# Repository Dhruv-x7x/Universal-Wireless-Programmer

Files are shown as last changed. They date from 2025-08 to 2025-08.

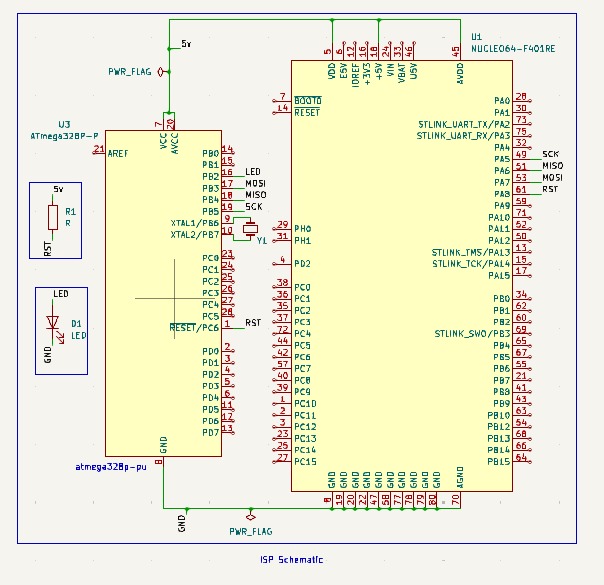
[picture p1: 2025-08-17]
others/ISP_schematic.jpeg

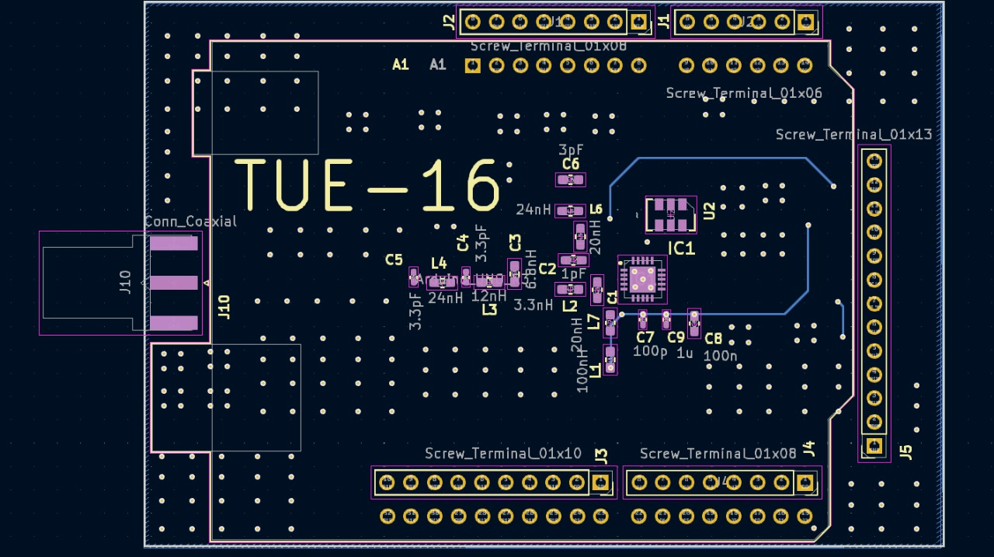
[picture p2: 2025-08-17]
pcb/PCB1/pictures/pcb_sch_back.jpeg

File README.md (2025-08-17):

Review Assignment Due Date (https://classroom.github.com/a/NJLWAR4a)
 

 
<!-- DON'T MODIFY ANYTHING ABOVE -->
<!-- Modify from here -->
## 📄 Project Documentation

###  Project Name: Universal Wireless Programmer
###  Team Number: TUE-16
###  Team Members:

Anay Malviya 22b1255

Dhruv Meena 22b1279

Hardik Pratap Gohil 22b1293

Kaustav Saha 22b1228

Saptarshi Biswas 22b1258

---

### 📌 Problem Statement and Solution:

Whether it's deep inside big industrial machines, remote terrains or disaster zones, there is always bots and embedded devices to perform critical tasks and send back important data to the users. The big limitation here is that **we have to physically access them to reprogram them and download data.** The **Universal Wireless Programmer** completely cuts off all cords as well as this big limiation. We designed a **wireless programming** and **data retrieval** system for microcontrollers and development boards like Arduino Uno and ATmega328P. We use **RF communication** to send compiled code and receive real-time data back, all over-the-air.

---

### 📚 Contents

- [src](./src) – Source code including firmware and scripts
- [pcb](./pcb) – PCB design files and schematics
- [reports](./reports) – Milestone reports
- [others](./others) – Other circuit diagrams and misc. info
- [3d_models](./3d_models) – 3D CAD files
- [README.md](./README.md) – Problem Statement
- [bom.xls](./bom.xls) – Bill of Materials

---

### 💡 Learnings
We tried a lot of approaches throughout the project to figure out programming since there were no easily available resources related to that. Firstly, we got stuck at figuring out how to make arduino enter into the bootloader mode. For that we tried a bunch of approaches:
1) Software reset - Using DTR and RTS (Failed due to no response from arduino)
2) Power reset - Using pmos (Failed due to insufficient current to turn on the arduino)
3) Power reset - Using power mosfet (Reset worked but failed to enter bootloader mode)
4) Using reset pin - Reset worked but failed to enter bootloader mod

There were some more variations of these methods and some more approaches which all failed until we randomly figured out that the RESET PULSE DURATION which we found in the documentation and used without questioning was not sufficient and tuned it to a higher value which worked

We also spent a lot of time on figuring out USB CDC which was not working. In this task, we were supposed to figure out communication between STM in USB Host mode and arduino as a CDC device. We got no response from arduino whatsoever in this step, so we moved on to using UART for programming.

As soon as we received the RF PCB, we tested it and it was working completely fine. So we started working on implementing the SPI protocol to use the SI4464 PCB for wireless communication. We thought the issue was in software and spent a lot of time figuring out the configuration of the drivers. However, later we checked the hardware again and found a VDD-ground short. We believe that this was due to lack of ESD protection on the IC. We implemented our backup using bluetooth and are working on the PCB 

These were the difficulties we faced but we found out alternative ways to get each of them working to get to a working prototype.

---

*This project was completed as a part of EDL Lab in Spring'25*

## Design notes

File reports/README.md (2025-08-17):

### Overview

`reports` directory contains all reports and presentations submitted for all milestones. Below is an overview of our project.

---

### Objectives
- **Python-based Communication Dashboard (GUI)**
  - Develop an intuitive graphical interface to upload and parse `.hex` files, initiate wireless connection, and receive as well as plot real-time serial data.
- **Bluetooth Communication using HC-05 Module**
  - Implement a basic communication protocol using the **HC-05** module to wirelessly transmit .hex files from the GUI to the target system in the first prototype.
- **STM32F401RE Board as a Wireless Programmer**
  - Program the STM32 board to receive the transmitted `.hex` file via UART from the HC-05 and program external devices through two different protocols:
    - **USB CDC**: Detect connected devices and program development boards such as the Arduino Uno using **STK500** protocol.
    - **In-System Programming (ISP)**: Implement low-level SPI communication to program standalone microcontrollers like the ATmega328P.
  - Include port detection and signature matching to ensure accurate device targeting and communication.
- **Design a Custom PCB with the SI4464 RF Transceiver**
  - Replace Bluetooth with the **SI4464** RF module in final prototype.
- **Implement Bi-Directional Communication**
  - Add data reception from the programmed device, enabling real-time serial monitoring and plotting on the GUI communication dashboard.

---

### Design Process

---

### Results

We successfully achieved the core objectives of our project by fully implementing the wireless transmission and reception pipeline. Our system enables `.hex` files to be sent over-the-air from our custom-built Python GUI to the STM32F401RE board, which then programs the target device. Once programmed, the target device transmits real-time data back to the STM32, which is displayed via the serial monitor integrated into the GUI.

We also designed and fabricated a custom PCB to replace the Bluetooth module with the SI4464 RF transceiver. However, due to our PCB not working as expected, we decided to go with our backup plan and use Bluetooth for the complete communication pipeline in the final prototype.

We also faced issues with the planned programming methods (USB CDC and ISP), so we implemented a third method using UART RX/TX communication directly with the target device. Due to challenges faced in receiving valid responses from the target using low-level SPI commands in the ISP protocol, and partial implementation of the USB CDC interface, we were forced to use the RX/TX pins. We successfully implemented the STK500 protocol over UART to communicate with the target microcontroller.

To demonstrate the functionality of our project, we wirelessly transmitted and programmed a simple `blink.ino` hex-file. The LED on the target device blinked at different intervals based on the uploaded program, validating our over-the-air programming. We also received simple UART messages on the serial monitor.

---

### Conclusions

Our system presents a practical and effective solution to the problem of remotely programming and communicating with embedded devices. We developed key technologies and wrote custom-firmware for various microcontrollers. There was a lot of learning involved, both technical and personal. We gained hands-on experience with serial communication protocols such as UART, SPI, and USB CDC. The entire protocol along with all the commands are ingrained in our brains. There were many challenges along the way, like in low-level SPI programming and USB CDC setups which we solved after long nights of debugging and research. We learned the importance of backup plans and the hurdles of integrating outdated or vaguely documented protocols. We developed debugging skills at both the hardware and software levels. 

The future scope of this project would include the following:
- **Upgrading from bluetooth to RFIC**: RFIC provides a much longer range of communication.
- **Implement USB/ISP protocols successfully**: Helps to extend to multiple other development boards and controllers.

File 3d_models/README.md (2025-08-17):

### 3D Models

We do not have any 3D models or components that requires laser cutting. Created directory to pass Actions.

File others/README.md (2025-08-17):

## Miscellaneous Files 

This directory contains all testing schematics, connections used for the final submissions as well as connections of methods we tried but could not get to work.

### Directory Structure
```plaintext
├── /others
  ├── demo_smart_cooling_system_schematic.jpeg
  ├── GUI_flowchart.jpeg
  ├── ISP_schematic.jpeg
  ├── uart_schematic.jpeg
  ├── usb_schematic.jpeg
  ├── User_Manual_Bluetooth.pdf
```

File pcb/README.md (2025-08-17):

### PCB

---

We only designed one PCB which houses the **SI4464** module to receive and transmit signals. You can find its description [here](https://github.com/edl-iitb/edl-25-project-submission-edl25_tue16/blob/main/pcb/PCB1/README.md). 

All other circuitry was tested on breadboard or soldered on to general purpose boards. Their relevant circuitry is organized under `others` directory.

---

#### Reasons for Issues with PCB

- Vdd and Gnd were shorted as SI4464 IC which didn't have ESD protection was somehow damaged.

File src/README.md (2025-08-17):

## Source Files

The `src` directory is organized as follows:

```plaintext
├── ArduinoUNO
├── Communication_Dashboard_GUI
├── STM32
├── README.md
```

Descriptions of these directories, terminal based commands and design execution flow are added to the `README.md` of the individual directories. 

---

#### General Description

- **ArduinoUNO**: contains `.ino` and `.c` files that are to be compiled using ArduinoIDE and uploaded as hex-files.
- **Communication_Dashboard_GUI**: contains code for the GUI
- **STM32**: contains the final code that has to be uploaded to NUCLEO board to make it into a programmer. Exact instructions are given in `/STM32/README.md`.

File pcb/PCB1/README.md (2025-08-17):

## PCB for SI4464 Transceiver 

The **SI4464 PCB** is a **2** layered PCB we designed that acts like a breakout board for the [SI4464 IC](https://www.silabs.com/wireless/proprietary/ezradiopro-sub-ghz-ics/device.si4464?tab=specs). It can be subdivided into 2 major portions:

- **Matching Network**
- **Connections to Header Pins**

---

### Matching Network: 
 - It has a trace (of higher width) coming from the SMA connector (that is attached to the antenna), that goes into a series of inductors and capacitors (the matching network), and finally into the IC. The layout for the matching network was optimised, and was kept similar to the layout given in [layout guidelines](https://www.silabs.com/documents/public/application-notes/AN629.pdf) for the IC.
 - **Decoupling capacitors** were also placed very close to the IC power input ports, as per the layout guidelines.
 - All the traces in these portions were made on the **front copper layer**.

### Header Pins for External Connection:
- We attached this PCB on the STM32 Nucleo-Board which blocked its pins and hence made a separate set of header pins on the top that were shorted to the original Nucleo board pins so that the pins underneath could be accessed from these.
- 2 traces for the connection of the header pin to the IC were done in the **bottom copper layer**.

### Directory Structure

```plaintext
  ├── /PCB1 
    ├── design.kicad_pcb # PCB Design in KiCAD format 
    ├── schematic.sch # KiCAD Schematic
    ├── README.md
    ├── pictures
      ├── ALL_LAYERS_PCB.jpg # Schematic from front
      ├── pcb_board.jpg # PCB Board without antenna
      ├── pcb_with_antenna.jpg # PCB Board with antenna
      ├── pcb_3d_front.jpeg # 3D view from front
      ├── pcb_3d_back # 3D view from back
      ├── pcb_sch_back.jpeg  # Schematic from back
```

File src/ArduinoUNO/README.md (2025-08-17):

# Arduino UNO

---

This directory contains the various scripts we used when programming Arduino UNO. To use them, simply download them and open them with ArduinoIDE or copy the code directly into ArduinoIDE. The scripts can be used for other Arduino boards by changing the `pin` definitions at the top. All Arduino code is used as hex-files. To generate hex-files, click `Compile as Binary` under `Sketch` tab of the ArduinoIDE. All code available here are in public domain.

The structure of the directory is as follows:

```plaintext
├── Blink.c
├── Bare_minimum.c
├── Fading.c
├── demo_smart_cooling_system.c
├── Liquid_crystals.c
├── README.md
```

---

- `Blink.c` simply turns LED off and on with a delay of 1 second. The current definition is for `Digital Pin 10` maps to `Pin 16` of the ATMEGA328P IC used on Arduino UNO.
- `Bare_minimum.c` is basically an empty file that is used for debugging purposes only.
- `Fading.c` makes the LED at pin 10 fade in and out.
- `ArduinoISP.ino` is another example code that we used when testing ISP protocol. We programmed the ATMEGA328P IC using Arduino UNO as a ISP programmer. To open this file in your ArduinoIDE go to `Examples > 11. ArduinoISP > ArduinoISP`. Please refer to the official documentation for the connections and further explanation. [Here](https://docs.arduino.cc/built-in-examples/arduino-isp/ArduinoISP/)
- `demo_smart_cooling_system.c` is code for our demonstration. To use this code, please refer to the connections given [here](https://github.com/edl-iitb/edl-25-project-submission-edl25_tue16/blob/main/others/demo_smart_cooling_system_schematic.jpeg). The goal of this demo is to have a fan that cools a temperature sensor **more** if the temperature rises by rotating faster and slowing down when the temperature drops (feedback loop).

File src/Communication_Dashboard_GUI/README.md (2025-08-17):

## Communication Dashboard GUI

This Python-based graphical user interface (GUI) tool provides a comprehensive solution for programming and interacting with embedded devices, specifically STM32 microcontrollers and target devices such as Arduino/ATMEGA328P. Our list of features include:

- **Hex File Upload & Generation**  
  Seamlessly upload hex-files from your system or generate hex files by compiling the Arduino code in the GUI. Ensure that you have ArduinoIDE installed in your local machine if you want to use the GUI to compile code and generate hex-file directly. 

- **Port Detection**  
  Automatically detect and verify the available serial ports for communication with the target device.

- **Signature Verification**  
  Ensure that the device signature on the STM32 matches the target device (Arduino/ATMEGA328P), guaranteeing proper identification.

- **Wireless Transmission**  
  Facilitate reliable wireless transmission of data to the target device.

- **Programming Status**  
  Receive clear feedback on whether the target device has been successfully programmed, with detailed status indicators on the GUI such as progress bars.

- **Serial Monitoring**  
  Monitor serial communication in real-time to track the status of data transfer and device responses.

- **Data Visualization**  
  Display real-time plots and data visualizations directly within the GUI for enhanced monitoring and analysis of the programming process.

---

## Installation

Follow these steps to install and run the application.

### Step 1: Clone the repository
First, clone the repository to your local machine using Git:

```bash
git clone https://github.com/edl-iitb/edl-25-project-submission-edl25_tue16.git
cd edl-25-project-submission-edl25_tue16/src/Communication_Dashboard_GUI
```

### Step 2: Create a Virtual Environment (Optional)

```bash
python -m venv venv
# On Windows, run this next: venv\Scripts\activate
# On macOS/Linux, run this next: source venv/bin/activate
```

### Step 3: Install Dependencies

```bash
pip install -r requirements.txt
```

### Step 4: Run the GUI

```bash
python GUI.py
```

---

## Using the GUI

#### Before you use our GUI ensure the following things:
- You have ArduinoIDE installed on your local machine.
- The transmitting PC should have the UART-HC-05 modules connected to its USB port.
- Install PL2303 Drivers for the HC-05 modules.
- The receiver PC should have the STM32-Arduino/ATMEGA328P modules connected to its USB port. Make the connections between STM32-Arduino/ATMEGA328P as given in `others/uart_schematic.jpeg`.
- A second HC-05 module must be connected to the STM32 and be successfully paired with the HC-05 on the transmitter side. You can find out how to pair HC-05 [here](https://howtomechatronics.com/tutorials/arduino/how-to-configure-pair-two-hc-05-bluetooth-module-master-slave-commands/).
- You have run `./STM32/UniversalWirelessProgrammer/Core/Src/main.c` on the STM32 board without errors. Refer [here](https://github.com/edl-iitb/edl-25-project-submission-edl25_tue16/blob/main/src/STM32/README.md) for the complete instructions on how to run `main.c` on STM32CubeIDE.
- You have familiriazed yourself with STK500 protocol which is used by Arduino and Atmel microcontrollers. Refer [here](https://ww1.microchip.com/downloads/en/AppNotes/doc2591.pdf). 

---

#### Follow these instructions to use our GUI:

- As soon as the GUI window pops up, you will notice there are already some logs in `Activity Log` window. This is supposed to happen as the GUI detects the Arduino CLI for code compilation.

Step 1

- Under `Board Selection`, select the target device you are programming. Current implementation only supports ArduinoUNO. Next, click on `Select Board` button and click `OK`.
- If you have already generated a hex-file before, click on `Load HEX File` button and find your hex-file.

Step 2

- If you want to compile the code on the GUI itself, click the `Arduino Code Editor` menu on the top and then write your code.
- Next, select the correct baudrate from the dropdown list. We have used **38400** in our case.
- Next to `COM Port`, select your port. If no port is visible, please click `Refresh Ports` and try again. Click `Connect`. If this was successful it will show **Connected** in `Activity Log` as well as below the `Refresh Ports` button in green. If you encounter an error, refer here.
- We are ready to program the target device now. Click `Check Signature`, if the target device was ArduinoUNO or ATMEGA328P you should receive back `1e 95 0f`. As well as `STK_INSYNC` and `STK_OK` after it. You should see `Signature Verified` on the top right corner. Error? Refer here.

Step 4

- Once the signature matching is successful, you can program the device whenever you want. Click `Program Device` and wait for the progress bar to finish.
- You can start serial monitoring by clicking `Serial Mode` on the bottom menu and serial plotting by clicking on `Serial Data Plotter` from the top menu bar.

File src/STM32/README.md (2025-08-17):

## STM32 Files

To run the STM32 programs, you will need to download STM32CubeIDE v1.18 from [here](https://www.st.com/en/development-tools/stm32cubeide.html). Setup the IDE as given on their website and open the `.project` file of the program you want to run on the STM32. If you only want to see the `main.c` file then go to `<directory-of-program-you-want-to-run>/Core/Src/main.c` within the STM32 directory.

First set up the GUI using the instructions given in `src/Communication_Dashboard_GUI/README.md`.

Follow these instructions to Run the programs on NUCLEO STM32-F401RE (you can run it on any NUCLEO STM32-FXXX series as long as it supports USB CDC):
- Download the entire directory you want to run on STM and then click `.project`. Navigate to `Core/Src/main.c`.
- Connect the STM32 to your PC via the cable given with the board.
- Under `Run`, click on `Debug Configurations`
- Go to `Debugger` and check `ST-LINK S/N`. Click `Scan`.
- If nothing is detected, please debug as given [here](https://stackoverflow.com/questions/44703157/no-st-link-detected-error-message-when-trying-to-connect-with-st-link-utility).
- If ST-LINK is detected, click `Apply` and then `Run`. If there are no errors, the board will be programmed successfully.

---

### Directory Structure

```plaintext
├── STM32
  ├── Receiver_Signature_LED_program
  ├── USB_Detect
  ├── HardcodeRXTX
  ├── UniversalWirelessProgrammer
```

#### Directory Descriptions
- Receiver_Signature_LED_program: Working Implementation of transfering hex-files through HC-05
- USB_Detect: Detecting USB devices using USB Enumeration Processes and through a female USB breakout board
- HardcodeRXTX: Complete Implementation of Programming Arduino via UART RX/TX
- UniversalWirelessProgrammer: Final Submission, incorporates the GUI with HardcodeRXTX

*Note: The above directories are solely for the STM32CubeIDE and can not contain README.md files. Therefore their descriptions are given here.*

---

## Using Universal Wireless Progammer with GUI

The state diagram given below explains the core working of the code. The STM is responding to the commands defined by us to perform all actions.

Flowchart

## Using STM

The STM has 3 wires correspondings to RESET(PB4), RX(PA10), TX(PA9) which need to be connected to arduino's or ISP's reset , TX and RX pins. Full connections are given in `others/uart_schematic.jpeg`.

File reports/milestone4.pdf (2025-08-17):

# Universal Wireless Programmer

Anay Malviya 22b1255
Dhruv Meena 22b1279
Hardik Pratap Gohil 22b1293 Kaustav Saha 22b1228
Saptarshi Biswas 332b1258

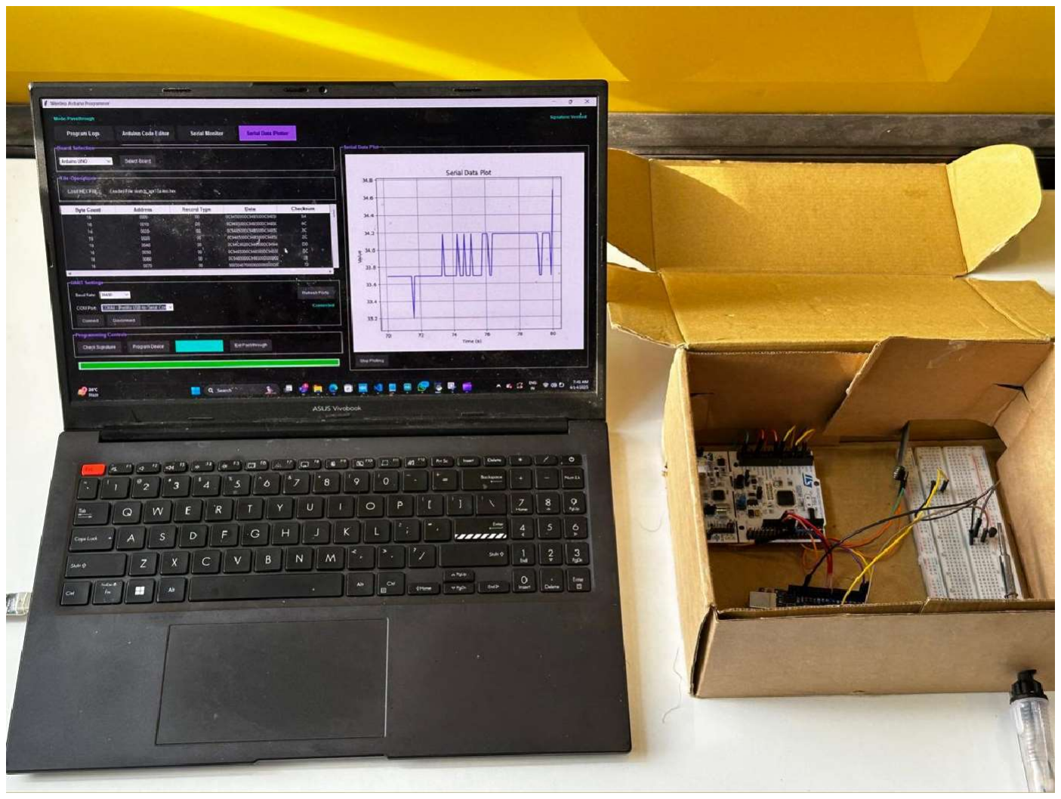
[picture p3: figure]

Our project is a Universal Wireless Programmer for microcontrollers. Engineers and developers will use it. It provides remote access to microcontrollers for programming and data retrieval.

# Status of project

Key specifications and requirements proposed at beginning of semester | Status at end of semester | Remarks/Justification
Python GUI | Complete
Wireless Communication | Partially Complete | Had to use our backup plan of Bluetooth communication rather than RF IC.
Programming Development Board | Complete
Programming Microcontroller IC | Complete
Wireless Serial Plotting and Monitoring | Complete

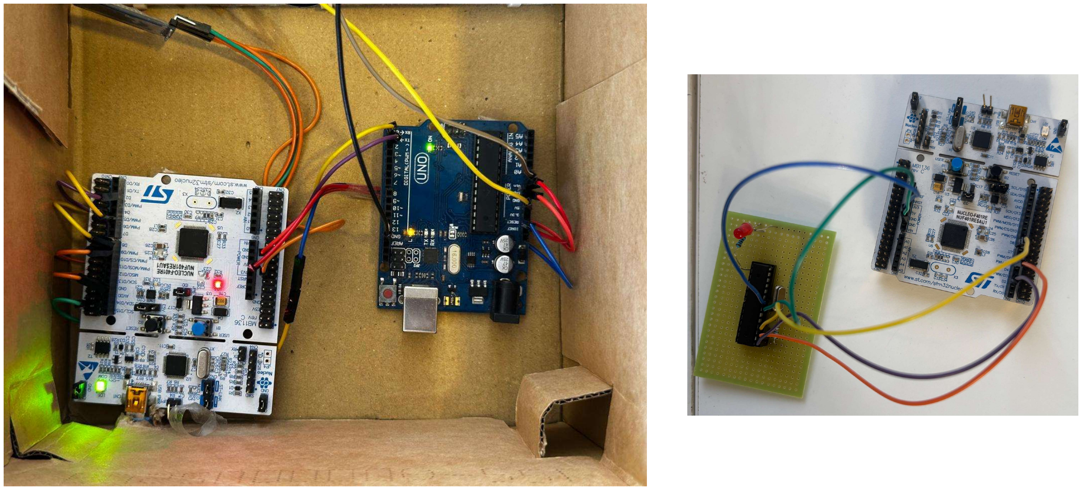
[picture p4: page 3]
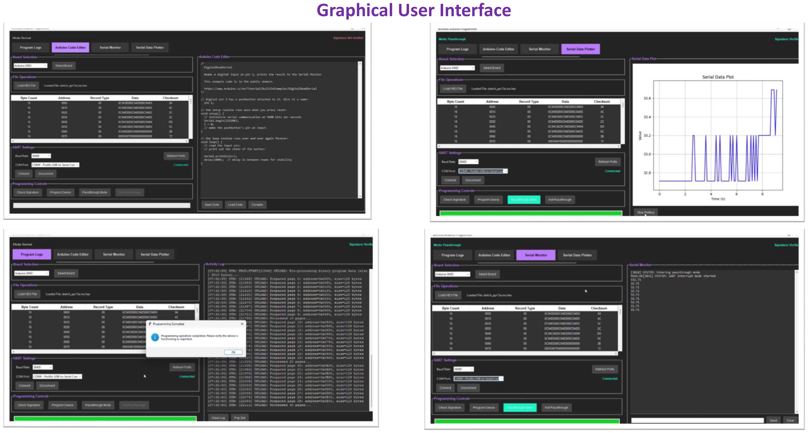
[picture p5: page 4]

### Graphical User Interface

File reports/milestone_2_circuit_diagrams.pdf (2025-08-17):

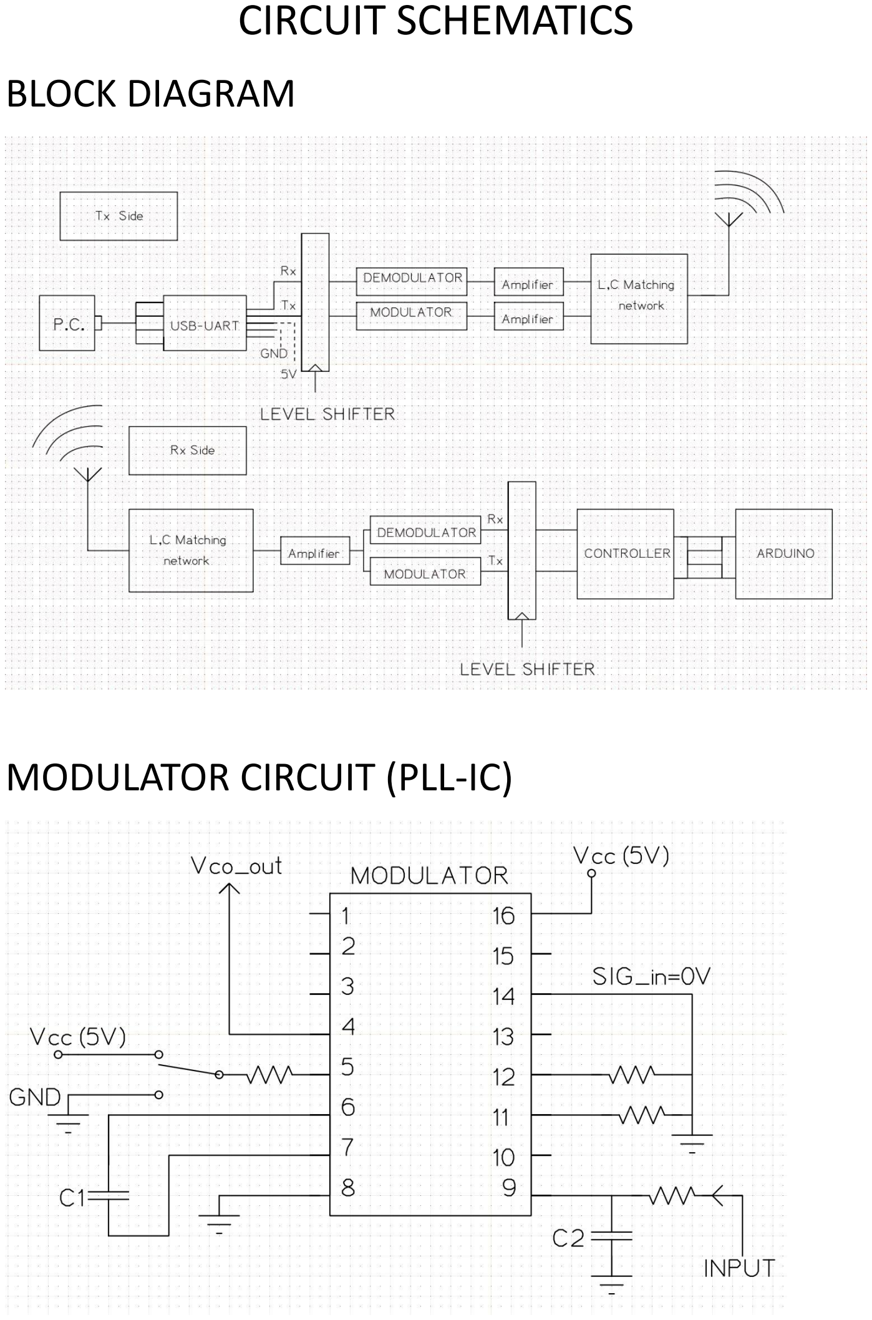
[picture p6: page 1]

CIRCUIT SCHEMATICS

BLOCK DIAGRAM

MODULATOR CIRCUIT (PLL-IC)

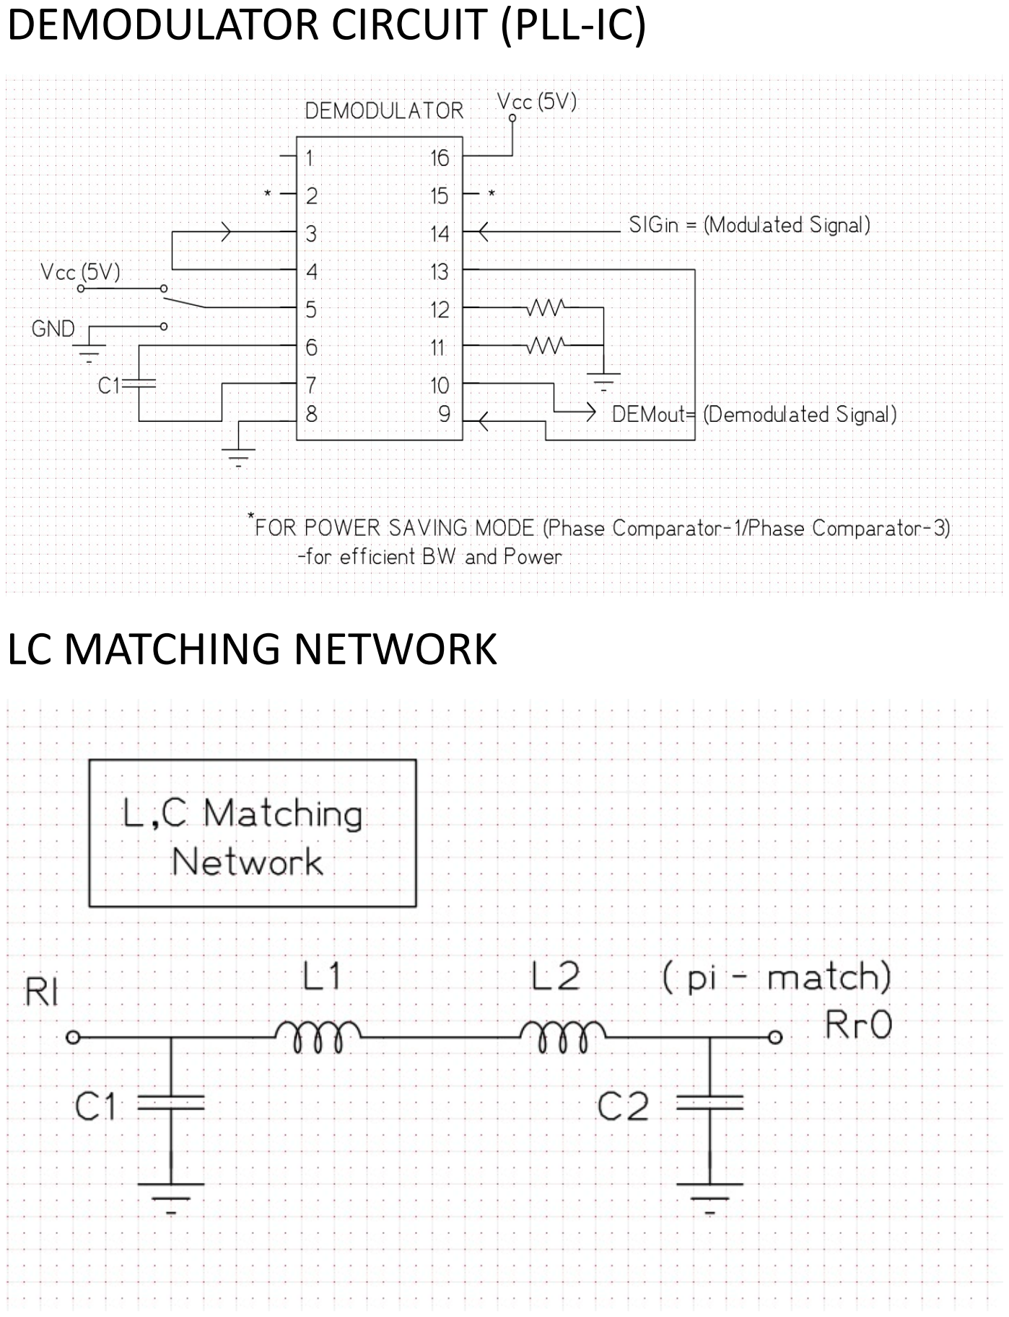
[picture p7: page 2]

DEMODULATOR CIRCUIT (PLL-IC)

LC MATCHING NETWORK

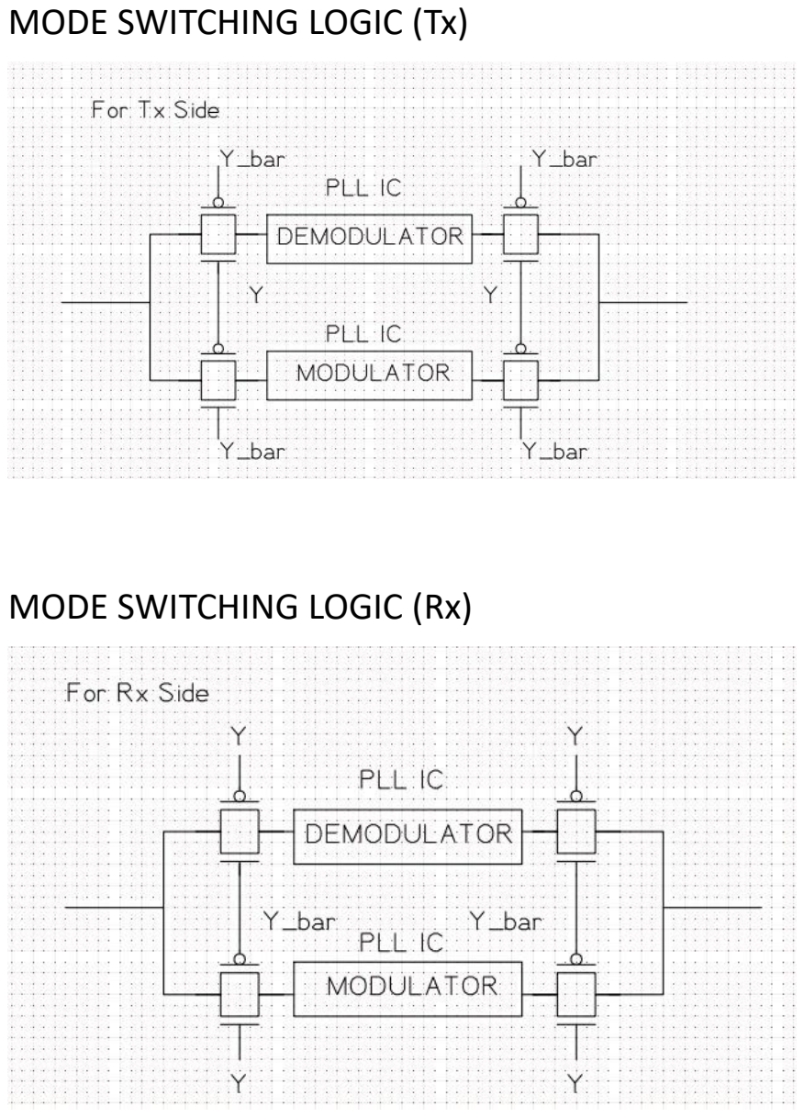
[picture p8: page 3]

MODE SWITCHING LOGIC (Tx)

MODE SWITCHING LOGIC (Rx)

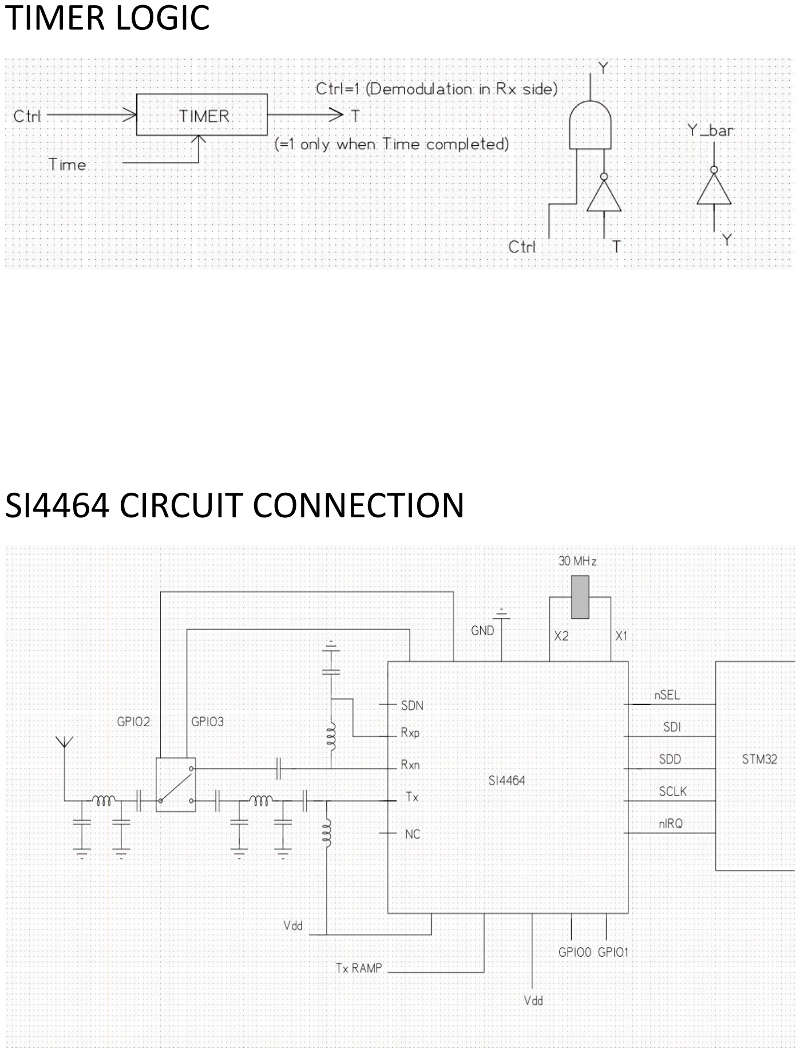
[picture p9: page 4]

TIMER LOGIC

SI4464 CIRCUIT CONNECTION

OVERALL CIRCUIT DESIGN

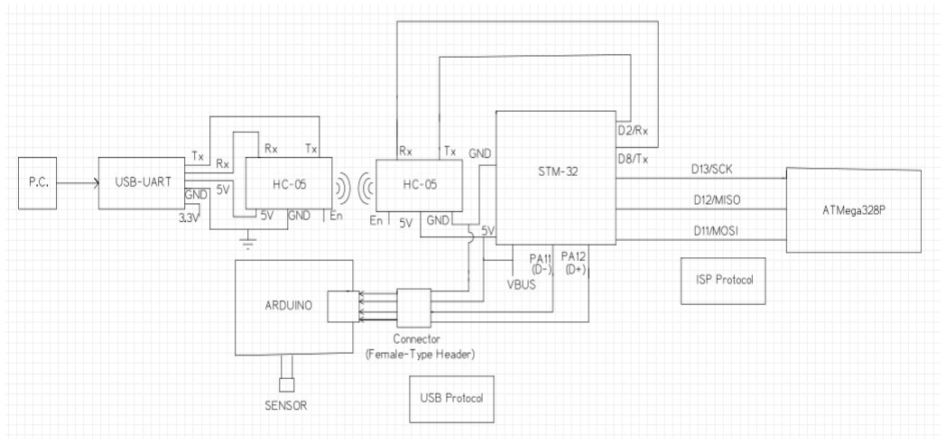
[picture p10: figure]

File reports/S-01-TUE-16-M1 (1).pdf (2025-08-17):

# UniversalWireless Programmer

# EDL Project

# S-01 Tue-16

D

e

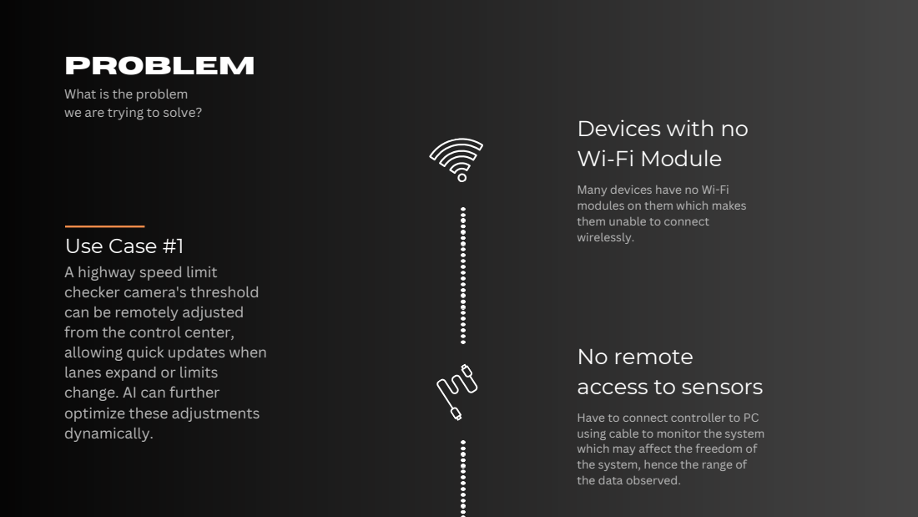
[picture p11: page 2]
wit; ule; hig; limit; win; uic; timiz; mic; y. Use Case

Problem What is the problem we are trying to solve?

vic
wirelessly. No re

Many devices have no Wi-Fi
modules on them which makes
them unable to connect

Have to connect controller to PC
using cable to monitor the system
which may affect the freedom of
the system, hence the range of
the data observed.

D

e

# vic

e

s

# wit

h

n

o

# Blu

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
# ule

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
Fi m

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
d. Use Case #2 As space manufacturing advances, our wireless programmers can be highly useful. With a superior antenna, they eliminate the hardware overhead and range issues of Wi-Fi and Bluetooth in space stations.

## Proposed Solution

What is the value proposition of our solution?

In a nutshell...

### Wireless Communication

We have our own communication module which removes the need for Wi-Fi or Bluetooth.

### Bi-directional Communication Channel

The bi-directional channel can get sensor readings wirelessly without having to waste RX TX ports.

### Custom RF Circuits

Tuned RF circuits that can be programmed by the user for specifications like range , data-rate, bandwidth and power-saving mode.

### Universal Programmer

Universality ensures that our programmer can adjust to any microcontroller.

### A pair of ICs with RF communication using FSK modulation, designed for

seamless wireless data transmission.

### The system includes a smart programmer that adapts to the end processor, ensuring compatibility across different platforms. This allows for universal integration with

various microcontrollers, FPGAs,

### and development boards

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
# ula

# tio

n

O

v

e

r
Wi-

Fi/

# Blu

e

t

o

o

t

h

# Alt

e

r

n

a

# tiv

e

s

Wi-Fi and Bluetooth were ruled out due to hardware overhead, internet dependency, and
unavailability in some
embedded devices.

FSK (Frequency Shift Keying) modulation was chosen for its reliability, noise resistance, and low power consumption.

The RF system operates
without internet, making it suitable for applications in IoT, space, and surveillance.

A

d

a

p

# tiv

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
# ele

c

# tio

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
# timiz

a

# tio

n

Low-bandwidth mode is used for short-range operations, while high-bandwidth mode enables long-range programming.

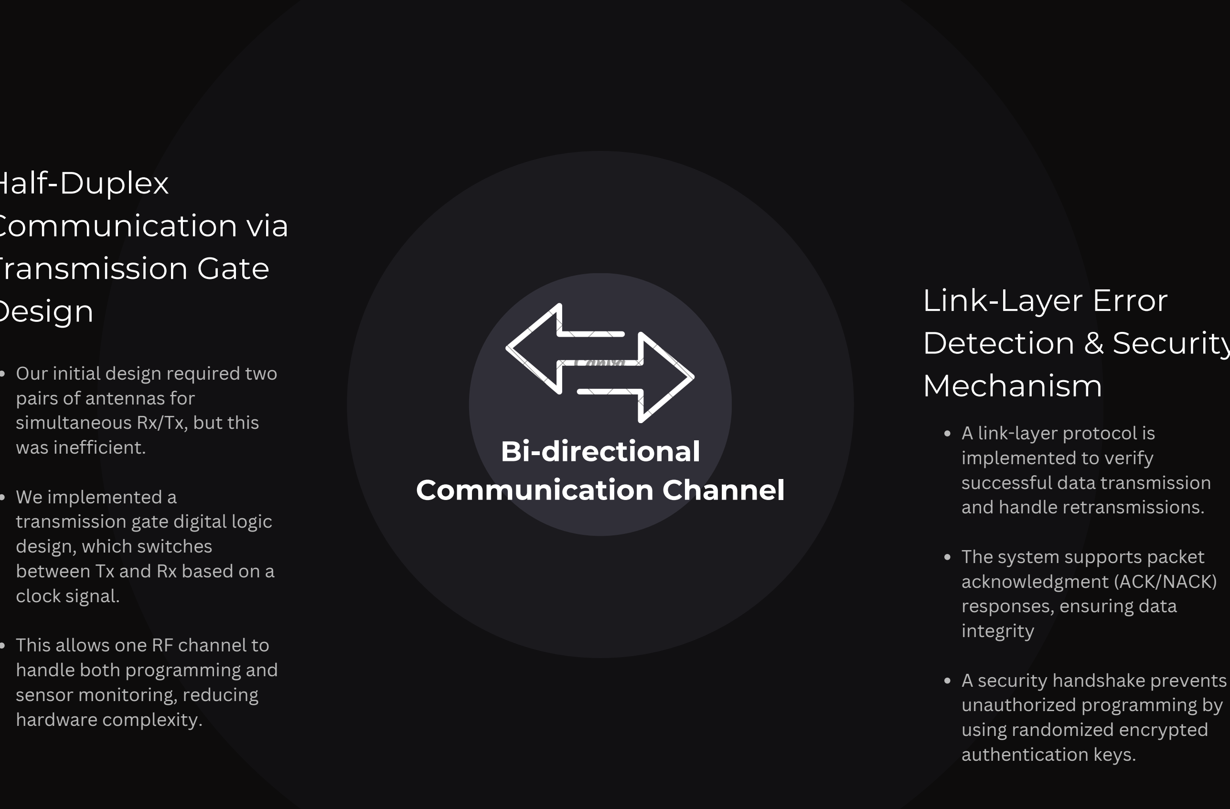
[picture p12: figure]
alf; ple; nic; tio; via; mis; sio; sig; Our initial design required two pairs of antennas for simultaneous Rx/Tx, but this was inefficient.; We implemented a transmission gate digital logic design, which switches between Tx and Rx based on a clock signal.; This allows one RF channel to handle both programming and sensor monitoring, reducing hardware complexity.; Lin; rit; nis; A link-layer protocol is implemented to verify successful data transmission and handle retransmissions.; The system supports packet acknowledgment (ACK/NACK) responses, ensuring data integrity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

H
C
T
D
y

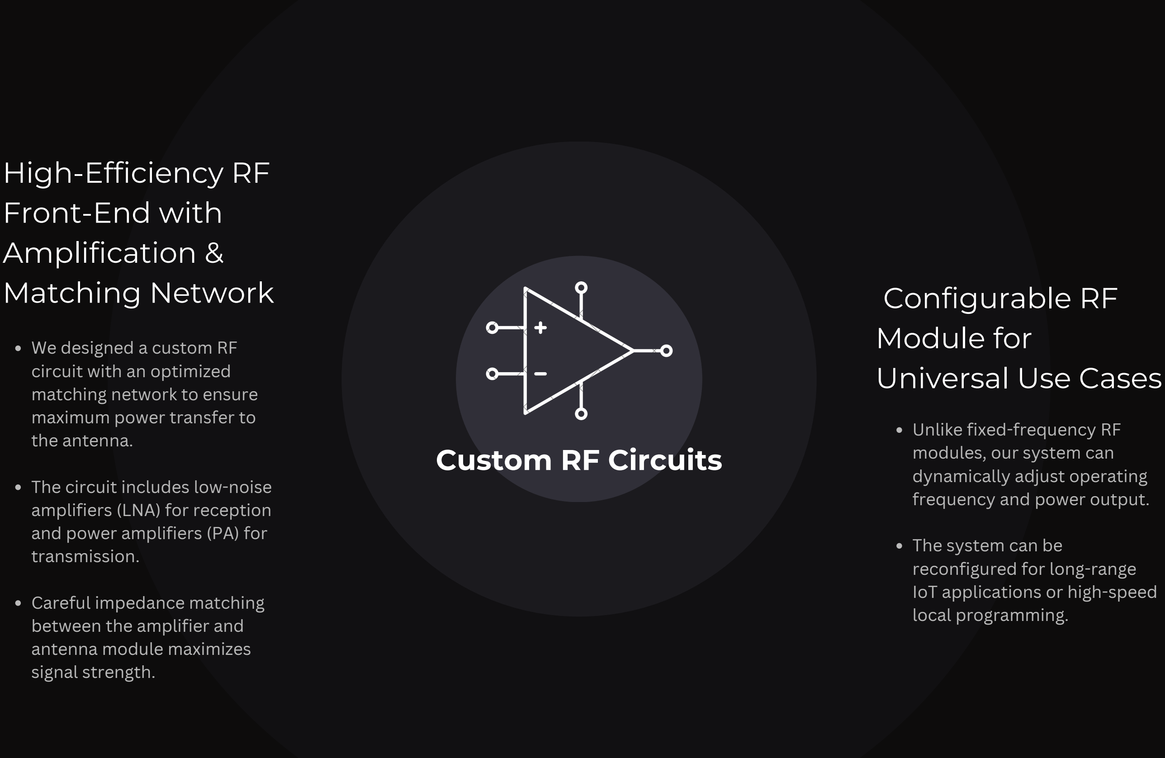
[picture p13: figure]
Hig; fficie; wit; plific; tio; hin; We designed a custom RF circuit with an optimized matching network to ensure maximum power transfer to the antenna.; The circuit includes low-noise amplifiers (LNA) for reception and power amplifiers (PA) for transmission.; Careful impedance matching between the amplifier and antenna module maximizes signal strength.; fig; ble; ule; niv; Unlike fixed-frequency RF modules, our system can dynamically adjust operating frequency and power output.; The system can be reconfigured for long-range IoT applications or high-speed local programming.

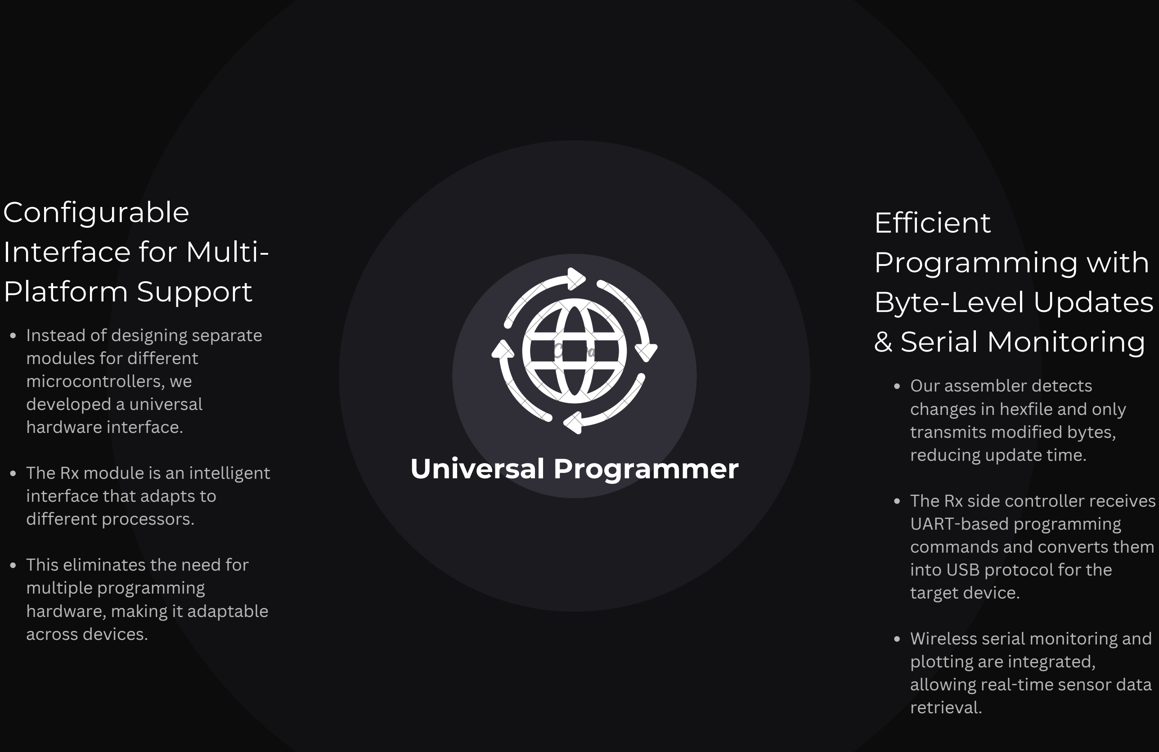
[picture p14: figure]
fig; ble Interface for M; ulti- Platform Support; Instead of designing separate modules for different microcontrollers, we developed a universal hardware interface.; The Rx module is an intelligent interface that adapts to different processors.; This eliminates the need for multiple programming hardware, making it adaptable across devices.; fficie; min; wit; rial M; nit; rin; Our assembler detects changes in hexfile and only transmits modified bytes, reducing update time.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

## Principle of Operation

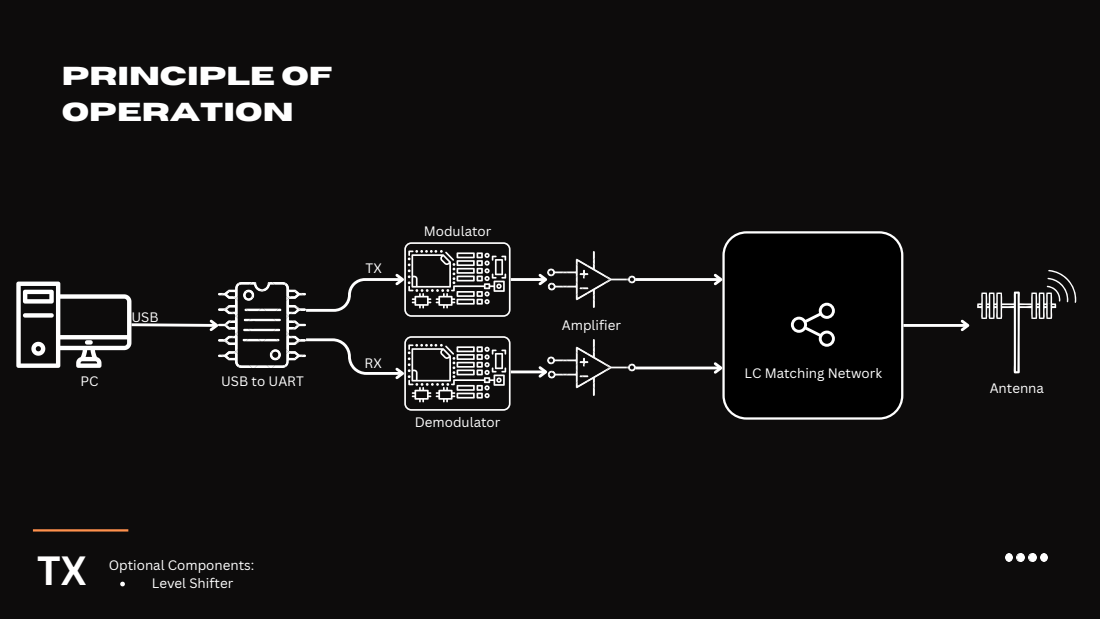
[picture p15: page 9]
USB; USB to UART; Modulator; Demodulator; Amplifier; Antenna; Optional Components: Level Shifter

LC Matching Network

## Principle of Operation

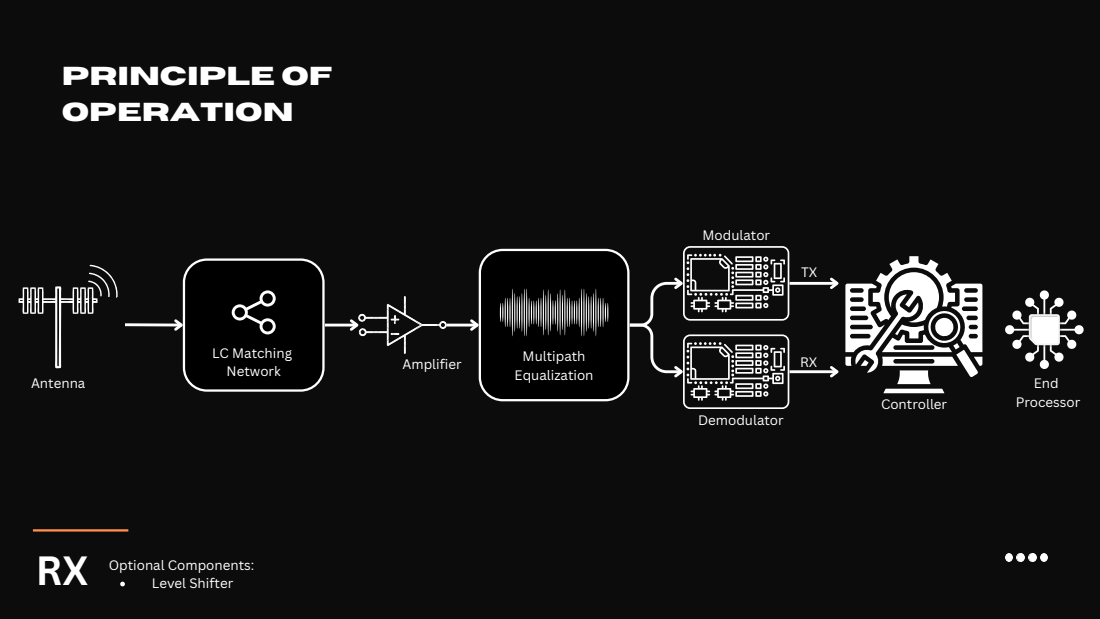
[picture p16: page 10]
Antenna; Modulator; Demodulator; Amplifier; LC Matching Network; Optional Components: Level Shifter; Multipath Equalization; Controller; End Processor

## Target Specifications

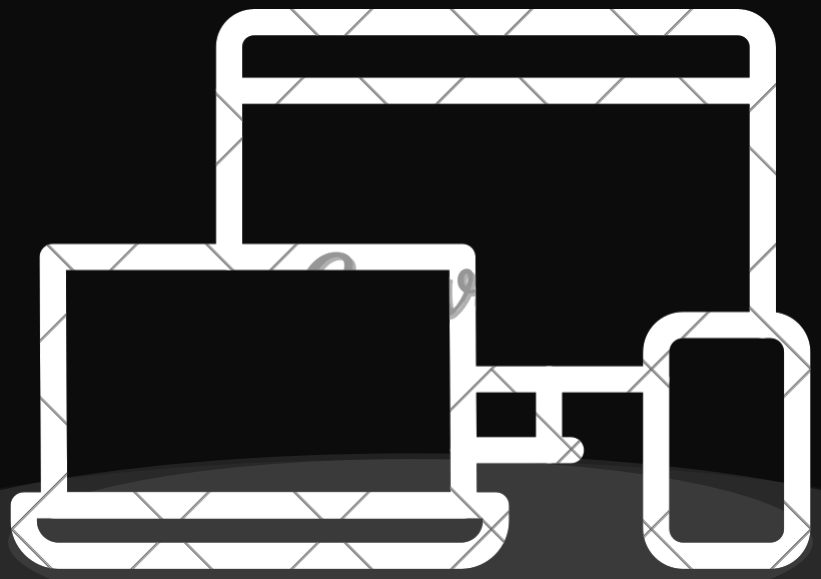
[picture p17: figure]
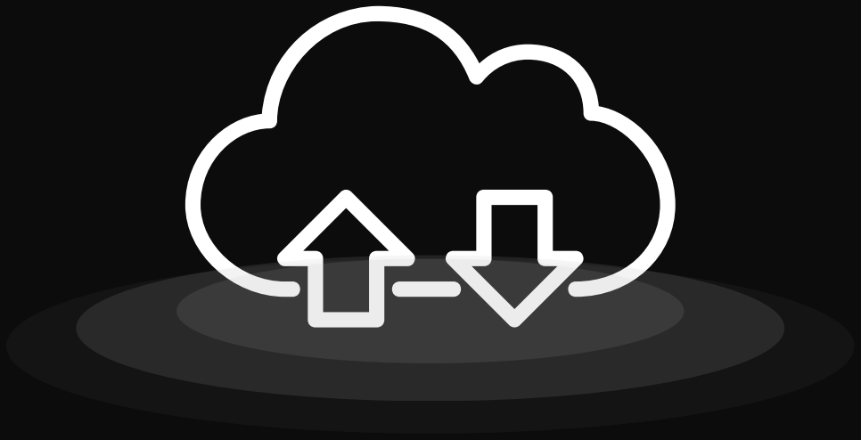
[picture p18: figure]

100 kbps Datarate | Compatible with atleast 2 Processors

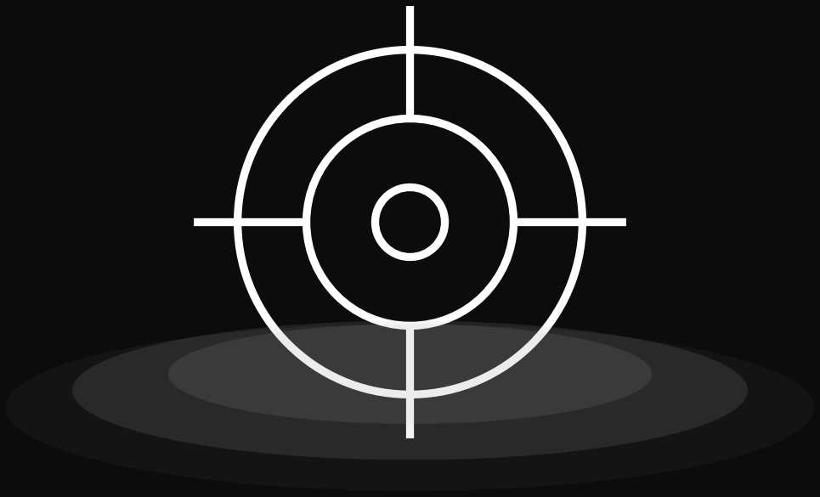
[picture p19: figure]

## Minimum 1m^2 Range

COMPONENTS | JUSTIFICATION
Tx Interface | Bidirectional USB to Serial converter. Available in WEL .
Level shifter | High slew rate and bandwidth
Modulator/Demodulator (PLL) | supports UART datarate, frequency separation of upto 20MHz.
Connector for Antenna | It is standard
Test board | Selected for demonstration as it is one of the most common development boards that does not support OTA programming
Test Sensor (e.g. temperature, ultrasonic, etc.,) | To demonstrate readings being sent back
AND GATE (for but not gate), NOT GATE, TRANSMISSION GATE | High speed THT logic IC to control switch between Forward and backward communication
High speed Comparator | High speed comparator. Available in WEL
Buffer | Buffer to store incoming and outgoing packets at various locations
Crystal Oscillator for timer module | To set a time for receiving data

KEY RISKS | MITIGATION STRATEGIES
Rx interference from other devices | User can select from a set of frequency bands
Transmission Range and SNR | Range and SNR improved by shifting to high power mode
Corrupted Data Received or failed transmission | ACK/NACK bits are sent to ensure that the transfer was successful

# Circuit Diagrams

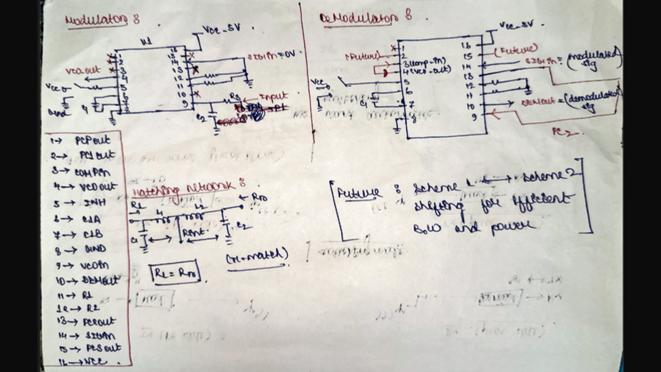
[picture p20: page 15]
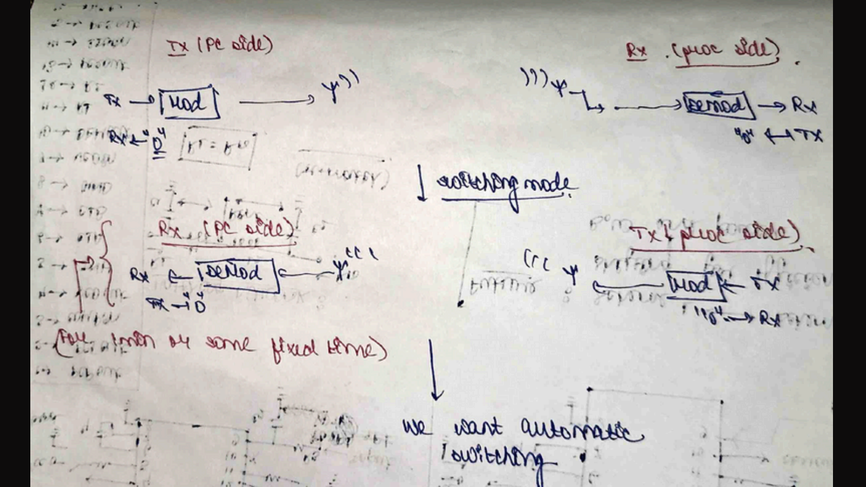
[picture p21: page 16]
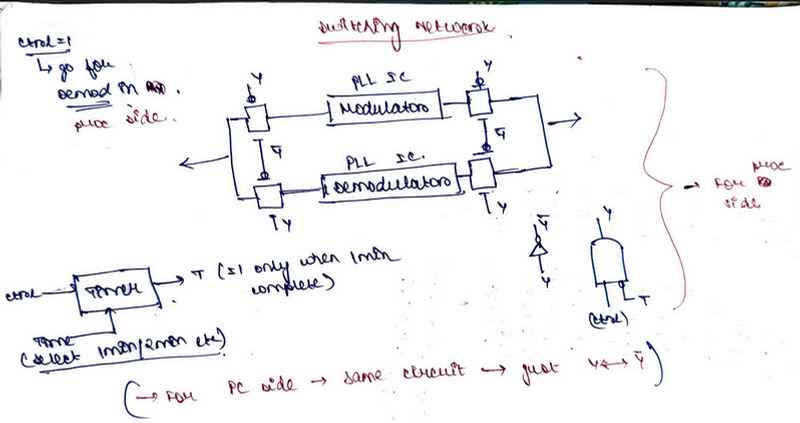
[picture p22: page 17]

# Deliverables

What are the expected outcomes
of the project?

## Successful wireless transmission of data from either side through a single pair of Antenna (programming/serial monitoring/sensor reading)

1.

Intelligent interface to adapt to different types of client protocols and configure the Rx

## accordingly

2.

3.Link layer to check if data was transmitted correctly or not, along with error detection

## 4.Application layer to give commands to initiate the communication 5.Adjustable data rate and bandwidth depending on range required and to save power GUI for serial monitoring/plotting, sensor reading, setting data rate, duration of a plotting/monitoring cycle

6.

## 7.Security protocol to ensure only specific Tx and Rx module pairs can communicate

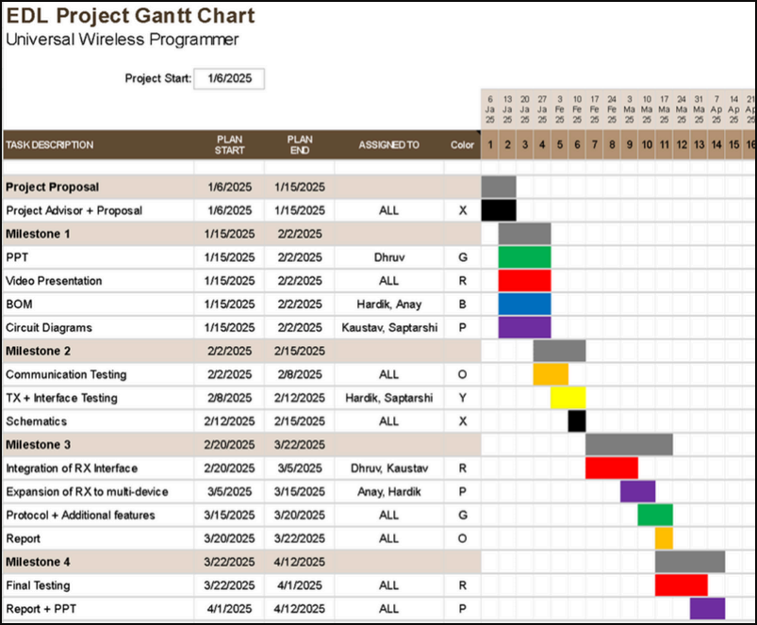
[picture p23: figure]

Weekly goals and work distributions are subject to changes.

# Thank You

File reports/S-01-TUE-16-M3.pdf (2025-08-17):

# UniversalWireless Programmer

## EDL Project

## S-01 Tue-16

## Feedback

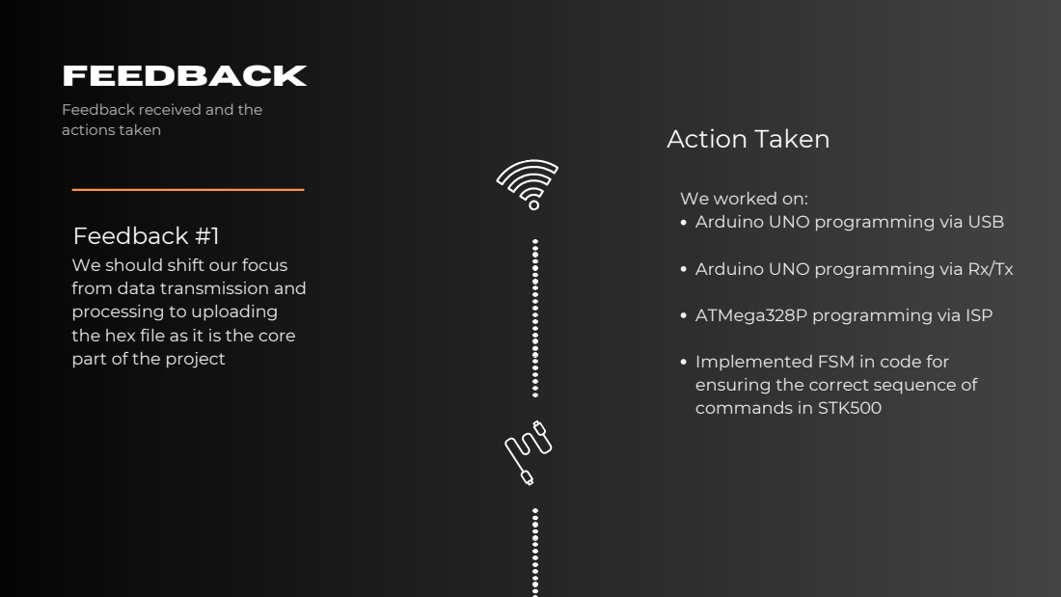
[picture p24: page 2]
actions taken; Action Taken

Feedback received and the

We worked on:
Arduino UNO programming via USB

Feedback #1
We should shift our focus
from data transmission and
processing to uploading
the hex file as it is the core
part of the project

Arduino UNO programming via Rx/Tx

ATMega328P programming via ISP

Implemented FSM in code for
ensuring the correct sequence of
commands in STK500

A

c

## tio

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
n. Successfully reset the Arduin

o
b

y

t

o

g

glin

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
B line which resets the board without need of any connection to be made by the user. Feedback #2 To get Arduino UNO board in bootloader mode, we had to reset the arduino using the DTR but we were unable to toggle the DTR. Feedback was to go with external reset pin initially to test the remaining logic.

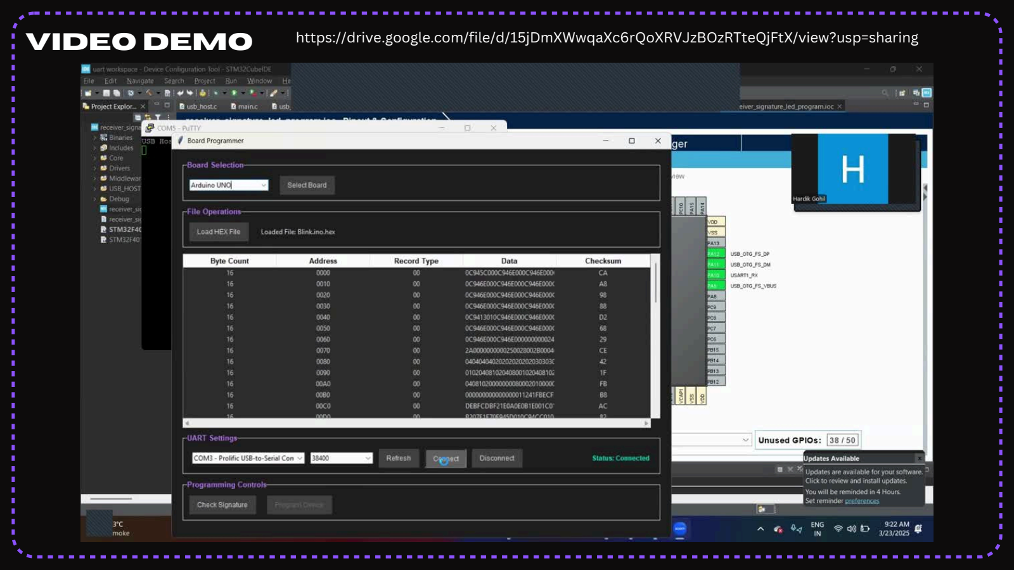
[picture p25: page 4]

Video Demo https://drive.google.com/file/d/15jDmXWwqaXc6rQoXRVJzBOzRTteQjFtX/view?usp=sharing

### PCB Stage

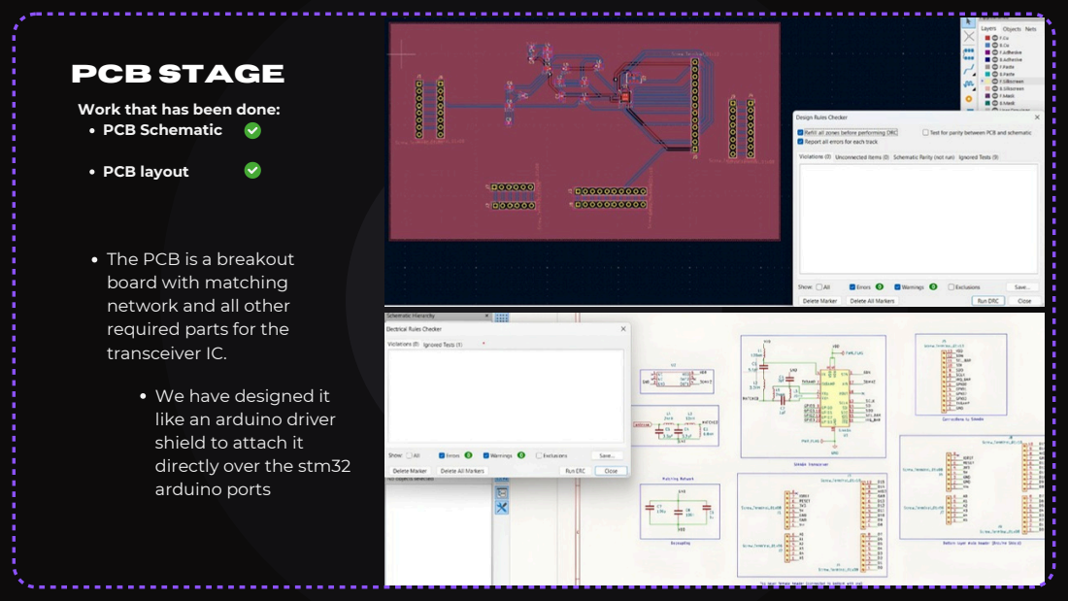
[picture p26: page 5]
PCB layout

Work that has been done:
PCB Schematic

The PCB is a breakout
board with matching
network and all other
required parts for the
transceiver IC.

We have designed it
like an arduino driver
shield to attach it
directly over the stm32
arduino ports


## PCB Form

The SI4464 IC for which we are making the breakout board arrived on this Tuesday

Trying to get the uploading of hex file to arduino done as it is the most crucial bottleneck of the project.

Earlier discussed and scheduled a review with
Maheshwar sir on 25th, March.

**However, we have completed the layout and resolved all errors and warning, to be reviewed this Tuesday.

We have not done reviews. The reasons for the delay are as follows:

ple; tly; ein; ble; uin; bly; pla; cin; wit; rial D; plo; din; file. Establish proper CDC communication between Arduino and STM to be able to communicate and transmit commands Work-in-progress; Incomplete

UI. Getting the Arduino in

Work in progress; Implemented a 2-FSK modulation-demodulation using CD74HC4046A; The IC is working correctly as was desired over a good frequency range.; **Custom RF Modulation-Demodulation testing; Critical / Incomplete Tasks

Reset using Vbus toggling is working fine but may cause an timing issue as the USB communication gets broken.; Replacing HC-05 with SI4464; Key Risks; ensuring proper working with the PCB.; Getting the bootloader on sync with STK500 protocol for the hex file to be flashed.

### Gantt chart deviations


# Original Gantt Chart

### Gantt chart deviations

## RFIC Breadboard Testing

We could not test the RFIC on breadboard. We have submitted our PCB design for the RFIC which we will test once we get it back.

## PCB Layout

Kaustav and Saptarshi were responsible for the layout The changes were made because we made a mistake in the Gantt chart earlier.

## Custom RF

We are no longer implementing custom RF due to insufficient time.

## Programming via USB

Since we could not complete programming the arduino via USB in milestone 2, we continued with the work for milestone 3.

## PCB Assembly

PCB assembly is not finished. We received the components really late and we only had to make a breakout board. So instead we focused on the programming part.

### Gantt chart deviations

# Updated Gantt Chart

### Work Distributions

## Code Upload on Arduino UNO

Responsible for dumping the hex file from STM to the Arduino UNO using the USB interface and Uart.

Team Member: Hardik, Anay

## Code Upload using ISP

This task involves programming the standalone ATmega328P microcontroller using an In-System Programmer (ISP)

Team Member: Dhruv, Saptarshi, Kaustav

## RF_IC Communication

This task involves transitioning from the HC-05 Bluetooth module to SI4464

Team Member: Kaustav, Saptarshi

## PCB Implementation

This task involves soldering components onto the PCB and conducting thorough testing for final demo

Team Member: All

### Final Demo Plan

Wireless Code Upload to Arduino Uno Development Board: Upload code wirelessly from a PC to the Arduino Uno using the Nucleo board as an intermediary, communicating via HC-05 Bluetooth or SI4464 RF IC — eliminating the need for USB connections.

Wireless Programming of Standalone ATmega328P Microcontroller: Wirelessly program the ATmega328P chip directly using the Nucleo board for In-System Programming (ISP).

# Thank You


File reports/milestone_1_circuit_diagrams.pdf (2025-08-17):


I ,

00 l
~ ! . L/
?- -- • i g

# Ii d

~


r
'
\~ ~----7~™~~\)\S'

\
\
\
\
~ ...,....--,----v .. -:-::i,
~------.

## .S-+ :t~H

,➔ u~
V-~ ~
➔ t)t~

# t\ ➔ R.l ; l

,.·:. 1:111
i~ ➔ R.L ,,,_ I ,

# ,i-t tu~

I

( ' \ I • •

I

I

•. J .

'

- j

, '

' > ,, ,, . .

,· ,


t·r 1•~~1, t,

t
,~
r
-,,

, , 't ,,
..,

l

,
'

" f ~

,, t
:..

. ;· .. ..

,,. ....
, .
.,, ..

### -... __ _

-'

,t, ., i ' ;- \ (' • | ~Jri,V
' ,
- ~ | - | ' .; | ' I . , • "

' .
-. ,;
- _., | f

. '


t;:====11 tt_tr\\)~

'f .•

' I

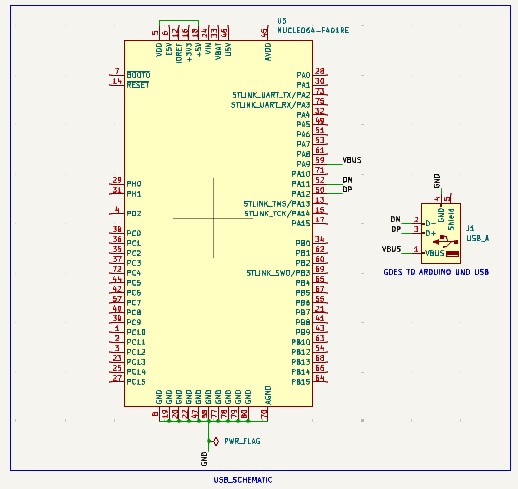
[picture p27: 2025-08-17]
others/usb_schematic.jpeg

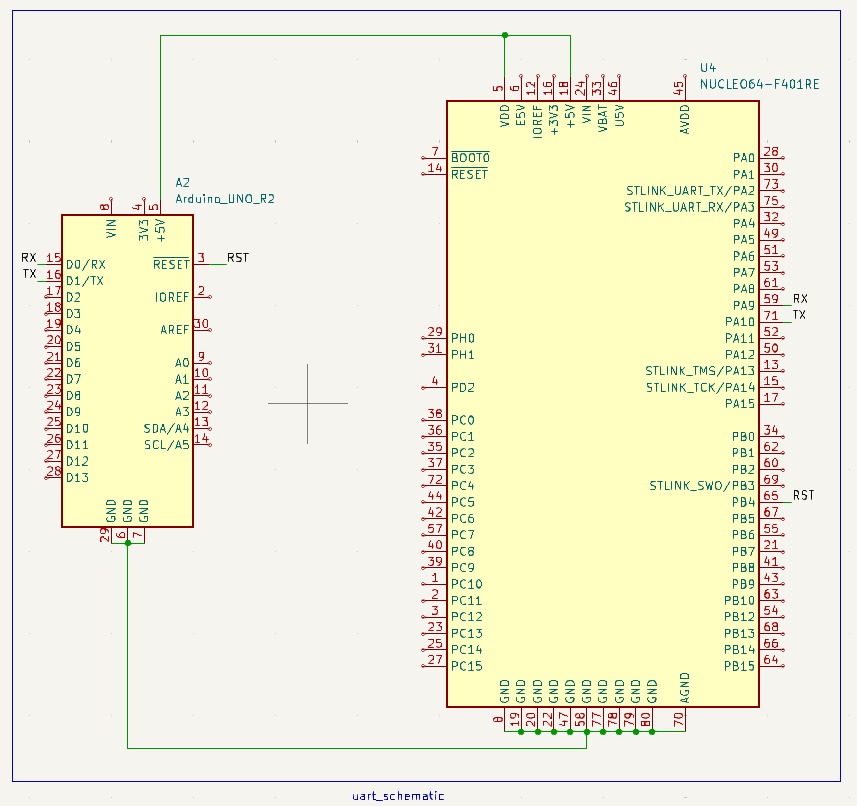
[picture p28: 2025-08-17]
others/uart_schematic.jpeg

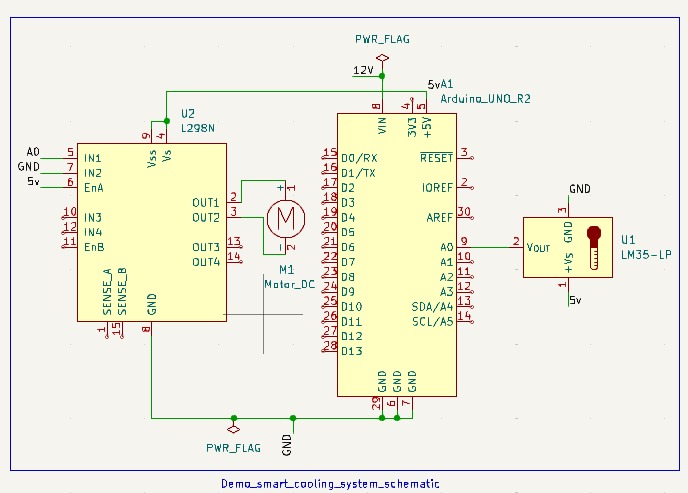
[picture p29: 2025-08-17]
others/demo_smart_cooling_system_schematic.jpeg

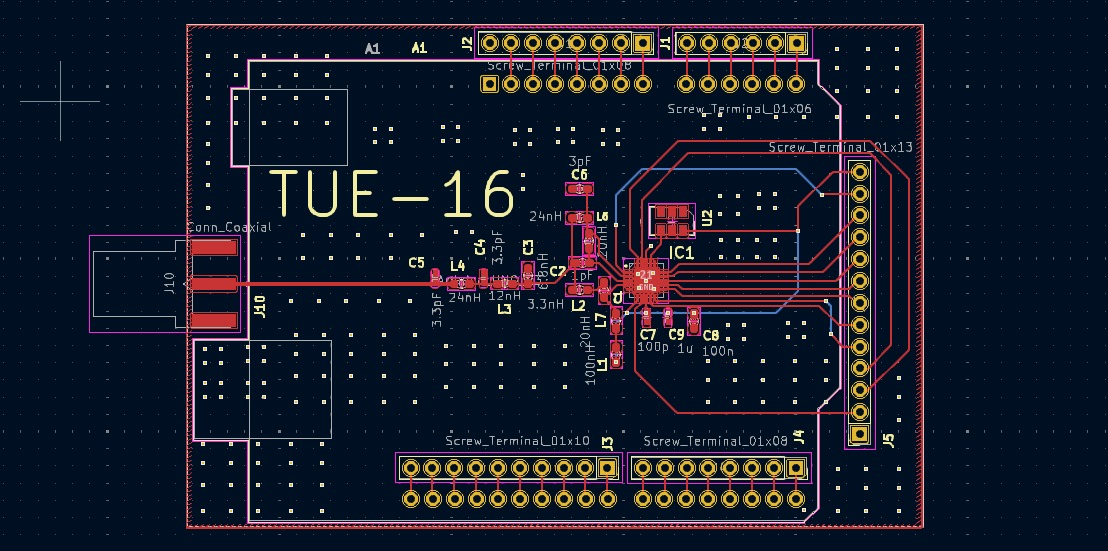
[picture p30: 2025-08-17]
pcb/PCB1/pictures/ALL_LAYERS_PCB.jpg

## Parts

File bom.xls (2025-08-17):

Project Title: Universal Wireless Programmer
Group ID: TUE-16, EDL-17, S01
Name of the Group Member/s: Dhruv, Kaustav, Hardik, Anay, Saptarshi
Contact details of the Group Member responsible for BOM: +91 89440 78285 KAUSTAV
BOM
Sr.No | Usage (Name of the "Circuit block/Functional block" in which components is used) | Part description (OpAMP,ADC,DAC etc) | Manufacturing Part Number | Package type/Footprint | Availiabile in WEL? | WEL Component stock Location-ID | Vendor | Stock Availiability (With Vendor) | Link (Vendor online website) | Required Qty + Spare | Cost per each item | Total Cost
1 | Tx Interface | USB to UART for reading data from laptop | PL2303 PL2303HX | PCB | Yes | 2L.BOX-1.4 | Robu | Out of Stock | https://robu.in/product/pl2303-pl2303hx-usb-ttl-module-5-pin/?gad_source=1 | 1+1 | 58 | 116
2 | Level shifter (PCB) | To match voltages with PLL IC | LM311 | 8SOIC | No | NA | Robu | In-Stock | https://robu.in/product/lm311dr-texas-instruments-analogue-comparator-high-speed-1-comparator-115-ns-3-5v-to-30v-soic-8-pins/ | 4+2 | 21 | 126
3 | Level shifter (Breadboard) | To match voltages with PLL IC | LM311 | DIP-8 | No | NA | Robu | In-Stock | https://robu.in/product/lm311-voltage-comparator-ic-dip-8-package/ | 4+2 | 31 | 186
4 | Modulator/Demodulator (Breadboard) | Phase Locked Loop for FSK | CD74HC4046A | PDIP-THT | No | NA | RsDelivers | In-Stock | https://in.rsdelivers.com/product/texas-instruments/cd74hc4046ae/texas-instruments-cd74hc4046ae-pll-circuit-1-6-v/6624589 | 4+2 | 65.99 | 395.94
5 | Modulator/Demodulator (PCB) | Phase Locked Loop for FSK | CD74HC4046A | SOIC-16 | No | NA | Mouser | In-Stock | https://www.mouser.in/ProductDetail/Texas-Instruments/CD74HC4046AM96?qs=d9gICRQKuCdWutjVrMRjEg%3D%3D | 4+2 | 65.05 | 390.3
4 | Wireless Communication | Antenna | - | - | Yes | - | - | - | - | 2+1 | - | 0
4 | Connector for Antenna | SMA connector | SMA connector | Connector | Yes | 2L.BOX-2.18 | Robu | In-Stock | https://robu.in/product/sma-jack-long-straight-pcb-mount/?msclkid=e48b7625b3a019517b4e11b845544938 | 2+0 | 99 | 198
5 | Female Type A USB | Breakout board | USB Female to 2.54mm Breakout Board with Direct 4P Adapter Board- 2Pcs | Adapter board | No | NA | Robu | In-Stock | https://robu.in/product/usb-female-to-2-54mm-breakout-board-with-direct-4p-adapter-board/ | 1+1 | 13 | 26
6 | Test board | Arduino | Arduino UNO R3 | Development board | No | NA | Robu | In-Stock | https://robu.in/product/arduino-uno-r3/ | 1+1 | 523.71 | 1047.42
7 | Test Sensor (e.g. temperature, ultrasonic, etc.,) | Ultrasonic sensor | HCSR-04 | THT | Yes | 1D | Robu | In-Stock | https://robu.in/product/hc-sr04-ultrasonic-range-finder/?msclkid=7816424070211e26de4725dd8a6d6082 | 1 | 57 | 57
8 | AND GATE (for but not gate)(Breadboard) | Logic IC | IRS2104 | PDIP-8 | No | NA | Robu | In-Stock | https://robu.in/product/ir2104-pdip-8-gate-driver/?msclkid=75e4bc76992f120cd334dbe89dab51bb | 1+1 | 99 | 198
8 | AND GATE (for but not gate)(PCB) | Logic IC | IRS2104 | SOIC-8 | No | NA | Robu | In-Stock | https://robu.in/product/ir2104s-soic-8-gate-driver/ (https://robu.in/product/ir2104-pdip-8-gate-driver/?msclkid=75e4bc76992f120cd334dbe89dab51bb) | 1+1 | 69 | 138
10 | Buffer(Breadboard) | IC | SN74LS365AN - TI | DIP-16 | No | NA | Robu | In-Stock | https://robu.in/product/sn74ls365an-texas-instruments-buffer-line-driver-74ls365-4-75-v-to-5-25-v-dip-16/ | 2+2 | 99 | 396
10 | Buffer(PCB) | IC | SN74F240 | SOIC-20 | Yes | 2K.BOX-7.20 | In | In-Stock | https://in.element14.com/texas-instruments/sn74f244dwr/buffer-line-driver-non-inverting/dp/2854593 | 2+2 | 69.23 | 276.92
11 | Not Gate(Breadboard) | Logic IC | 74HC04 | PDIP-14 | Yes | 2L.BOX-1.20 | Digikey | In-Stock | https://www.mouser.in/ProductDetail/Nexperia/74HCU04N?qs=84A%2FDAdkstKhp9SrFWMgSA%3D%3D (https://www.digikey.in/en/htmldatasheets/production/1318507/0/0/1/74hc14) | 6+2 | 29 | 232
11 | Not Gate(PCB) | Logic IC | 74HC14 | SOIC | Yes | 2L.BOX-4.25 | Robu | In-Stock | https://robu.in/product/74hc14d653-nexperia-logic-ic-inverter-hex-1-inputs-14-pins-soic-74hc14/ (https://www.digikey.in/en/htmldatasheets/production/1318507/0/0/1/74hc14) | 2+2 | 35 | 140
12 | Transmission Gate (Breadboard) | Switching IC | CD4066-BE | DIP | No | NA | Robu | In-Stock | https://robu.in/product/cd4066-be-20-v-11-spst-4-channel-analog-switch-ic/ | 2+2 | 29 | 116
12 | Transmission Gate (PCB) | Switching IC | CD4066-BE | SOIC-14 | No | NA | Robu | In-Stock | https://robu.in/product/cd4066bm96-texas-instruments-bilateral-switch-quad-soic-14/ | 2+2 | 29 | 116
13 | Crystal Oscillator for timer module | Crystals | YXC-Y-26 | DIP 2 pin | No | NA | Robu | In-Stock | https://robu.in/product/yt-26-32-768khz-12-5pf-10ppm-2pin-dip-through-hole-cylinder-crystal-pack-of-2/ | 1+1 | 18 | 36
14 | Intermediate Controller for protocol | Microcontroller IC | STMF103RB | - | Yes | 2K.BOX-9.143 | Mouser | In-Stock | https://www.mouser.in/ProductDetail/STMicroelectronics/STM32F103RBT6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 | 1+1 | 609.65 | 1219.3
15 | Counter (Breadboard) | Counter IC | CD40102BE-Texas Instruments | 16-PDIP | NO | NA | Robu | In- Stock | https://robu.in/product/cd40102be-texas-instruments-inc-counter-ic-bcd-counter-2-element-4-bit-positive-edge-16-pdip/ | 8+6 | 85 | 1190
15 | Counter (PCB) | Counter IC | CD40102BE-Texas Instruments | SMD/SMT | NO | NA | Robu | In- Stock | https://robu.in/product/cd40102be-texas-instruments-inc-counter-ic-bcd-counter-2-element-4-bit-positive-edge-16-pdip/ | 8+6 | 85 | 1190
16 | High speed amplifier (Breadboard) | Opamp | MC33078 - Texas Instruments | DIP-8 | No | NA | Robu | In- Stock | https://robu.in/product/mc33078-dual-high-speed-low-noise-op-amp-ic-dip-8-package/ | 4+2 | 99 | 594
16 | High speed amplifier (PCB) | Opamp | MC33078 - Texas Instruments | DIP-8 | No | NA | Robu | In- Stock | https://robu.in/product/mc33078dt-stmicroelectronics-mc33078dt-operational-amplifier-dual-15-mhz-7-v-%c2%b5s-%c2%b1-2-5v-to-%c2%b1-15v-soic-8-pins/ (https://robu.in/product/mc33078-dual-high-speed-low-noise-op-amp-ic-dip-8-package/) | 4+2 | 31 | 186
17 | High Speed DAC(PCB) | IC | DAC908E | SOIC | NO | Na | Digikey | In-Stock | https://www.digikey.in/en/products/detail/texas-instruments/DAC908E/362187 | 2+2 | 770 | 3080
17 | High Speed DAC (Breadboard) | IC | DAC0808 | DIP-16 | NO | Na | Robu | In-Stock | https://robu.in/product/dac0808-8-bit-digital-to-analog-d-a-converter-ic-dip-16-package/ (https://www.digikey.in/en/products/detail/texas-instruments/DAC908E/362187) | 2+2 | 149 | 596
18 | Passive Components (RLC) | - | - | - | Yes | - | - | - | - | - | - | 0
19 | DigiPot | Tuning amplification and matching network | MCP42010 | DIP | Yes | 2L.BOX-2.33 | Digikey | In-Stock | https://www.digikey.in/en/products/detail/microchip-technology/MCP42010-I-P/362084 | 2+0 | 262.2 | 524.4
20 | Analog to Digital Converter(Breadboard) | IC | ADC0808CCN | DIP | No | NA | Robu | In-Stock | https://robu.in/product/adc0808ccn-pdip-28-analog-to-digital-converter-adc/ | 2+2 | 169 | 676
21 | Analog to Digital Converter(PCB) | IC | 579-MCP3008-I/SL | SOIC-16 | No | NA | Mouser | In-Stock | https://www.mouser.in/ProductDetail/Microchip-Technology/MCP3008-I-SL?qs=BYQkrObauiuZK6Atf%2FfReA%3D%3D | 2+2 | 226.85 | 907.4
21 | Xen 10 | FPGA board | - | - | Yes | - | - | - | - | 1 | - | 0
22 | SD Card | Micro- SD card | SKU: 1529089 | - | No | NA | Robu | In-Stock | https://robu.in/product/sandisk-micro-sd-sdhc-8gb-class-4-memory-card/ | 1 | 354 | 354
23 | Bluetooth Module (intial prototype) | Wireless Bluetooth Module for Rx/Tx | Bluetooth Module (HC-05) | Through hole | Yes | 2L.BOX-1.1 | ElectronicsComp | In-Stock | HC-05 Bluetooth Module with TTL Output buy online at Low Price in India - ElectronicsComp.com (https://www.electronicscomp.com/hc-05-bluetooth-module-buy-in-india?gQT=2) | 2+2 | 195 | 780
24 | Socket to attach ICs | To plug-in processor ICs for programming (using ISP) | ZIF SOCKET (28 PIN) | Socket | Yes | 2L.BOX-1.36 | Adafruit Industries | In-Stock | NEW PRODUCT – 28-pin ZIF IC Socket « Adafruit Industries – Makers, hackers, artists, designers and engineers! (https://blog.adafruit.com/2011/06/20/new-product-28-pin-zif-socket/) | 1+1 | 159 | 318
25 | Frequency Multiplier (PCB) | To increase the frequency (in custom RF) | CDCS504TPWRQ1 | TSSOP | No | NA | Digikey | In-Stock | CDCS504TPWRQ1 Texas Instruments | Integrated Circuits (ICs) | DigiKey (https://www.digikey.in/en/products/detail/texas-instruments/CDCS504TPWRQ1/7244173) | 4+2 | 128 | 768
25 | Frequency Multiplier (Breadboard) | To increase the frequency (in custom RF) | CDCS504TPWRQ1 | THT | No | NA | Digikey | In-Stock | CDCS504TPWRQ1 Texas Instruments | Integrated Circuits (ICs) | DigiKey (https://www.digikey.in/en/products/detail/texas-instruments/CDCS504TPWRQ1/7244173) | 4+2 | 128 | 768
26 | Frequency Divider (D flip flops) | To decrease the frequency (in custom RF) | SN74AC74NE4 | THT | no | NA | Mouser | In-Stock | SN74AC74NE4 Texas Instruments | Mouser India (https://www.mouser.in/ProductDetail/Texas-Instruments/SN74AC74NE4?qs=pdM4geFiyZRC4XQUJjnrrw%3D%3D) | 6+2 | 115 | 920
27 | Volatge Regulator | To convert 5V to 3.3V (used by MCU and frequency multipliers/dividers) | LM2596S-3.3 | TO-263 | no | NA | DigiKey | In-Stock | https://www.digikey.in/en/products/detail/texas-instruments/LM2596S-3-3-NOPB/363704 | 2+2 | 578 | 2312
28 | Arduino microcontroller IC | For demosntrating programming using ISP | ATmega328p | DIP-28 | Yes | 2L.BOX-2.63 | Digikey | In-Stock | https://www.digikey.in/en/products/detail/microchip-technology/ATMEGA328P-PU/1914589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 | 1+1 | 252.55 | 505.1
29 | stm32 nucleo board | For the MCU (in the first prototype) |  | Development Board | Yes | 1N | Mouser | In-Stock | https://www.mouser.in/ProductDetail/STMicroelectronics/X-NUCLEO-NFC02A1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 | 2+0 | 866.53 | 866.53
30 | RF IC for mod/demod | Replacing HC05 | SI4461 | 20VFQFN | No | NA | Digikey | In-Stock | https://www.digikey.in/en/products/detail/silicon-labs/SI4461-B1B-FMR/4069321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 | 2+2 | 733.84 | 2935.36
31 | 30MHz Oscillator | Clock | XLH536030.000000I | ceramic packaging | No | NA | Robu | In-Stock | https://stgaws.robu.in/product/xlh536030-000000i-oscillator/ | 2+2 | 199 | 796
 |  |  |  |  |  |  |  |  |  |  | Total | 25677.67
 | Note: If parts/components are not available online but can be available with local shop, then please mentioned in the vendor column as "Local"

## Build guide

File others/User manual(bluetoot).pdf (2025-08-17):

## USER MANUAL (Universal Wireless Programmer)

1) Power the STM with the uploaded code(named BluetoothFinal in github) of Universal Wireless Programmer (using the power supply of the development board/ microcontroller chip) in the system
2) The STM has 3 wires correspondings to RESET(PB4), RX(PA10), TX(PA9) which need to be connected to arduino's or ISP's reset , TX and RX pins
3) Connect the PL2303 converter which is linked to HC05 on your laptop
4) Open the GUI and load the hex file to be uploaded and connect to the USB-UART module
5) Select board, Check signature and see the activity logs for any verbose messages
6) Program the device. Observe it on your remote system and then enter the Serial mode to observe any serial data to see the print statements coming from arduino
7) Observe any integer data on the Serial plotter

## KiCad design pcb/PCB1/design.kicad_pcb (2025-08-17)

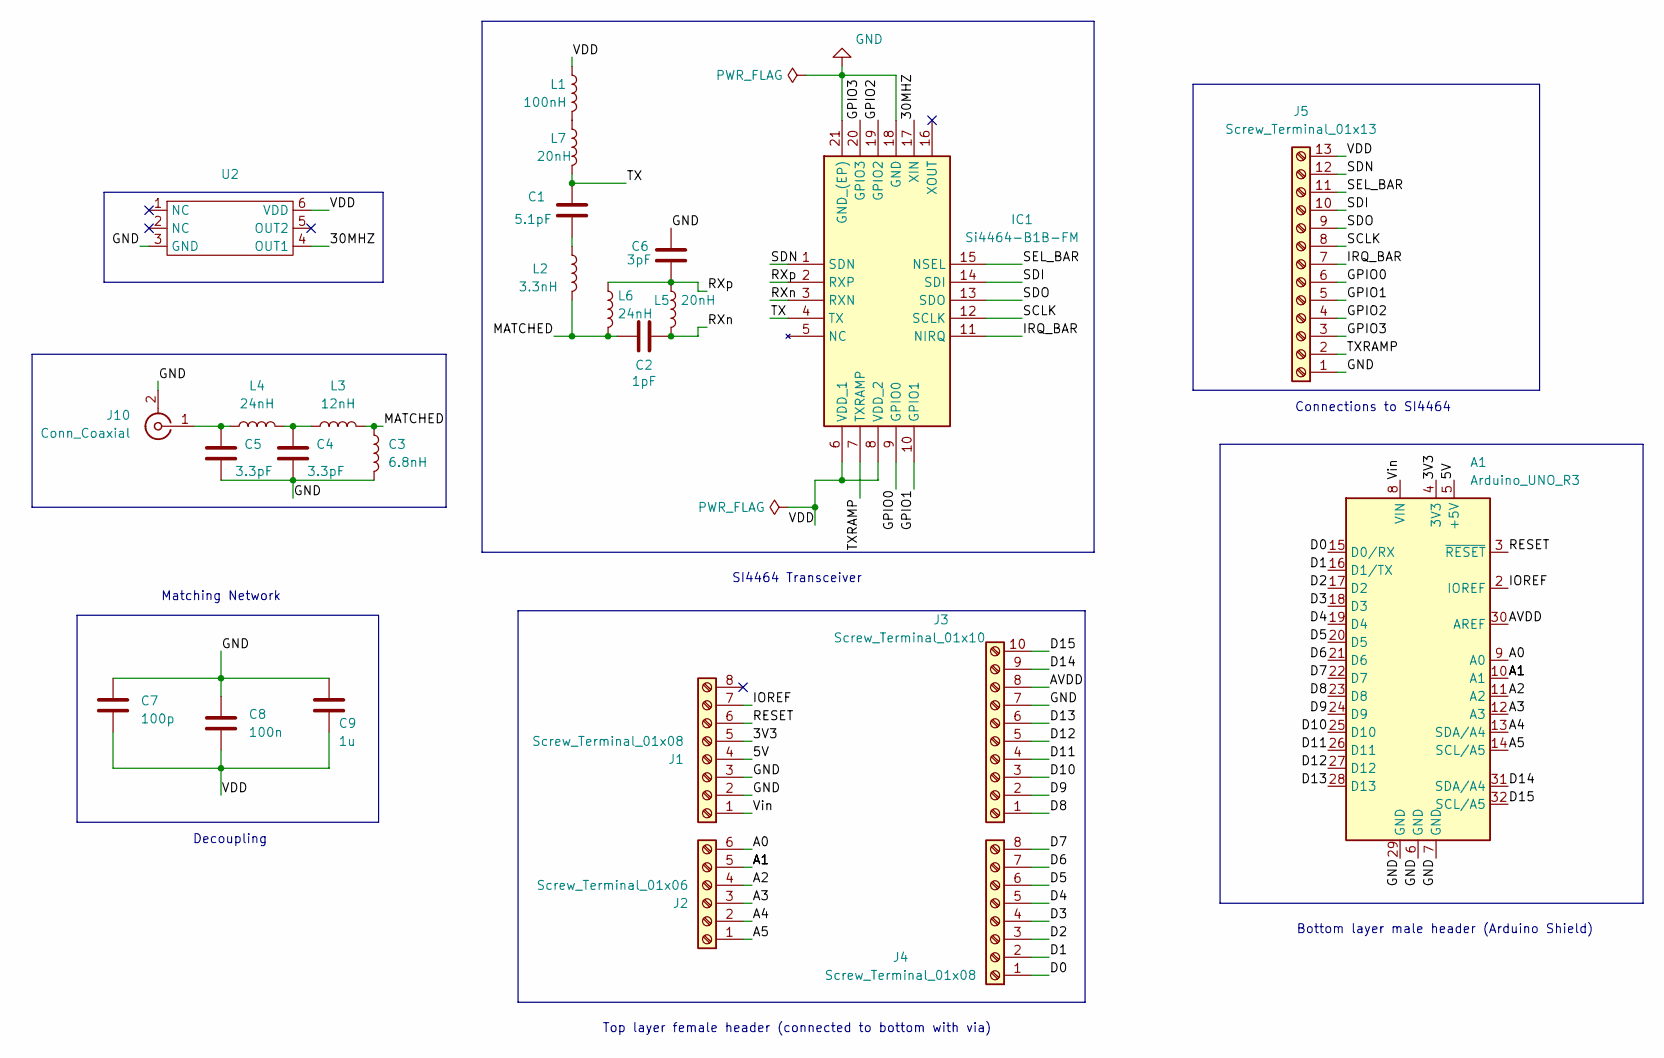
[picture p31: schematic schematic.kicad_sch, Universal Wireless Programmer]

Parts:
A1: Arduino_UNO_R3
C1: 5.1pF; C_0603_1608Metric_Pad1.08x0.95mm_HandSolder
C2: 1pF; C_0603_1608Metric_Pad1.08x0.95mm_HandSolder
C3: 6.8nH; L_0603_1608Metric_Pad1.05x0.95mm_HandSolder
C4, C5: 3.3pF; C_0402_1005Metric_Pad0.74x0.62mm_HandSolder
C6: 3pF; C_0603_1608Metric_Pad1.08x0.95mm_HandSolder
C7: 100p; C_0402_1005Metric_Pad0.74x0.62mm_HandSolder
C8: 100n; C_0603_1608Metric_Pad1.08x0.95mm_HandSolder
C9: 1u; C_0402_1005Metric_Pad0.74x0.62mm_HandSolder
IC1: Si4464-B1B-FM; QFN50P400X400X90-21N; Mouser Part Number 634-SI4464-B1X-FM
J1, J4: Screw_Terminal_01x08; PinSocket_1x08_P2.54mm_Vertical
J2: Screw_Terminal_01x06; PinSocket_1x06_P2.54mm_Vertical
J3: Screw_Terminal_01x10; PinSocket_1x10_P2.54mm_Vertical
J5: Screw_Terminal_01x13; PinSocket_1x13_P2.54mm_Vertical
J10: Conn_Coaxial; SMA_Amphenol_132289_EdgeMount
L1: 100nH; L_0603_1608Metric_Pad1.05x0.95mm_HandSolder
L2: 3.3nH; L_0603_1608Metric_Pad1.05x0.95mm_HandSolder
L3: 12nH; L_0603_1608Metric_Pad1.05x0.95mm_HandSolder
L4, L6: 24nH; L_0603_1608Metric_Pad1.05x0.95mm_HandSolder
L5, L7: 20nH; L_0603_1608Metric_Pad1.05x0.95mm_HandSolder
U2: Oscillator_SMD_IDT_JS6-6_5.0x3.2mm_P1.27mm

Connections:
/3V3: A1.4 (3V3), J1.5
/5V: A1.5 (+5V), J1.4
/30MHZ: IC1.17 (XIN), U2.4 (OUT1)
/A0: A1.9 (A0), J2.6
/A1: A1.10 (A1), J2.5
/A2: A1.11 (A2), J2.4
/A3: A1.12 (A3), J2.3
/A4: A1.13 (SDA/A4), J2.2
/A5: A1.14 (SCL/A5), J2.1
/AVDD: A1.30 (AREF), J3.8
/D0: A1.15 (D0/RX), J4.1
/D1: A1.16 (D1/TX), J4.2
/D2: A1.17 (D2), J4.3
/D3: A1.18 (D3), J4.4
/D4: A1.19 (D4), J4.5
/D5: A1.20 (D5), J4.6
/D6: A1.21 (D6), J4.7
/D7: A1.22 (D7), J4.8
/D8: A1.23 (D8), J3.1
/D9: A1.24 (D9), J3.2
/D10: A1.25 (D10), J3.3
/D11: A1.26 (D11), J3.4
/D12: A1.27 (D12), J3.5
/D13: A1.28 (D13), J3.6
/D14: A1.31 (SDA/A4), J3.9
/D15: A1.32 (SCL/A5), J3.10
/GPIO0: IC1.9 (GPIO0), J5.6
/GPIO1: IC1.10 (GPIO1), J5.5
/GPIO2: IC1.19 (GPIO2), J5.4
/GPIO3: IC1.20 (GPIO3), J5.3
/IOREF: A1.2 (IOREF), J1.7
/IRQ_BAR: IC1.11 (NIRQ), J5.7
/MATCHED: C2.1, C3.1, L2.2, L3.2, L6.2
/RESET: A1.3 (~RESET), J1.6
/RXn: C2.2, IC1.3 (RXN), L5.2
/RXp: C6.2, IC1.2 (RXP), L5.1, L6.1
/SCLK: IC1.12 (SCLK), J5.8
/SDI: IC1.14 (SDI), J5.10
/SDN: IC1.1 (SDN), J5.12
/SDO: IC1.13 (SDO), J5.9
/SEL_BAR: IC1.15 (NSEL), J5.11
/TX: C1.1, IC1.4 (TX), L7.2
/TXRAMP: IC1.7 (TXRAMP), J5.2
/VDD: C7.2, C8.2, C9.2, IC1.6 (VDD_1), IC1.8 (VDD_2), J5.13, L1.1, U2.6 (VDD)
/Vin: A1.8 (VIN), J1.1
GND: A1.6 (GND), A1.7 (GND), A1.29 (GND), C3.2, C4.2, C5.2, C6.1, C7.1, C8.1, C9.1, IC1.18 (GND), IC1.21 (GND_(EP)), J1.2, J1.3, J3.7, J5.1, J10.2 (Ext), U2.3 (GND)
unnamed: C1.2, L2.1
unnamed: C4.1, L3.1, L4.2
unnamed: C5.1, J10.1 (In), L4.1
unnamed: L1.2, L7.1

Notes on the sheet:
Connections to SI4464
Decoupling
Top layer female header (connected to bottom with via)
Bottom layer male header (Arduino Shield)
SI4464 Transceiver
Matching Network

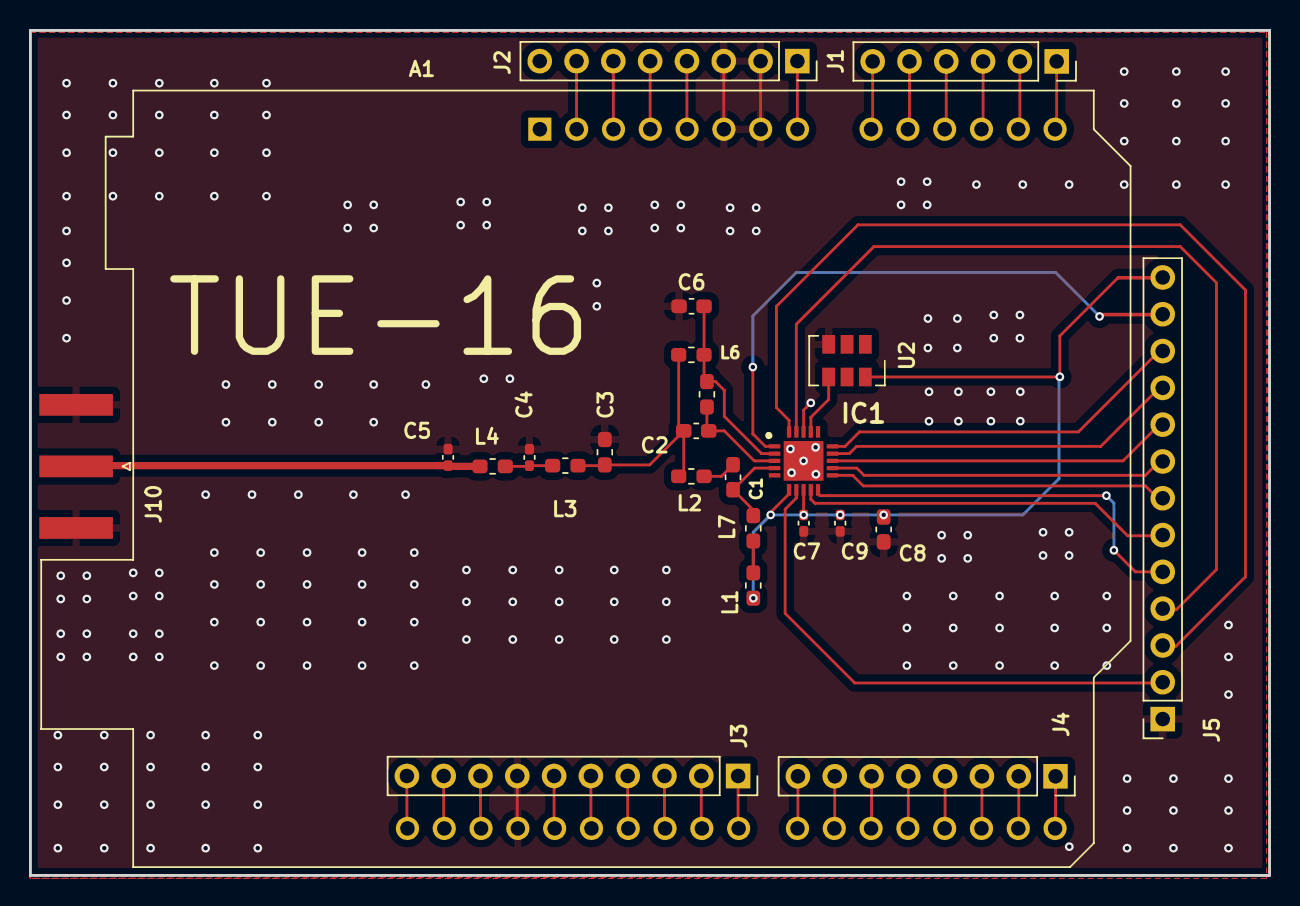
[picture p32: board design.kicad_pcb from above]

Board: 2 copper layers, 85.5 x 58.3 mm, 25 parts (0 on the bottom side), 50 nets.

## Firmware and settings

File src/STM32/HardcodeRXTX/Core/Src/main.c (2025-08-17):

/* GLOBAL DEFINITIONS - DO NOT REMOVE THIS SECTION */
// Define all protocol constants at the top level to ensure visibility
#define STK_GET_SYNC               0x30  // Command: Get Sync
#define STK_GET_SYNC_EXT           0x20  // Command param: Get Sync (extended)
#define STK_INSYNC                 0x14  // Response: In Sync
#define STK_OK                     0x10  // Response: OK

// Arduino parameters
#define ARDUINO_RESET_PIN          GPIO_PIN_4
#define ARDUINO_RESET_PORT         GPIOB
#define ARDUINO_BOOTLOADER_TIMEOUT 1500  // UNO bootloader active window (~1.5 seconds)
#define ARDUINO_SYNC_RETRIES       10    // Increased number of sync attempts
#define ARDUINO_RESET_TIMEOUT      800   // Timeout for Arduino to respond after reset
#define MAX_RESET_ATTEMPTS         5     // Increased number of reset attempts

// Reset timing parameters (in ms)
#define RESET_PULSE_DURATION       2000  // Much longer reset pulse for visible LED blink
#define POST_RESET_DELAY           250   // Increased wait time after reset
#define INTER_RESET_DELAY          1000  // Longer delay between reset attempts
#define SYNC_RETRY_DELAY           100   // Delay between sync command retries

// Response timeouts
#define SYNC_RESPONSE_TIMEOUT      500   // Increased timeout for sync response
#define SECOND_BYTE_TIMEOUT        300   // Dedicated timeout for second byte

// Buffer and UART settings
#define UART_TIMEOUT               1000
#define RX_BUFFER_SIZE             256
#define DEBUG_BUFFER_SIZE          512

// Feature flags
#define DTR_CONTROL_ENABLED        1
#define VERBOSE_DEBUG_ENABLED      1
#define DIRECT_SYNC_COMMAND        1
/* END OF GLOBAL DEFINITIONS */

/* STK500 Protocol Commands for Hex File Upload */
#define STK_LOAD_ADDRESS         0x55  // Command: Load Address
#define STK_PROG_PAGE            0x64  // Command: Program Page
#define STK_READ_PAGE            0x74  // Command: Read Page
#define STK_READ_SIGN            0x75  // Command: Read Signature
#define STK_LEAVE_PROGMODE       0x51  // Command: Leave Programming Mode
#define STK_ENTER_PROGMODE       0x50  // Command: Enter Programming Mode
#define STK_UNIVERSAL            0x56  // Command: Universal
#define STK_CHIP_ERASE           0x52  // Command: Chip erase (ATmega328P)

/* ATmega328P Memory Specifications */
#define FLASH_PAGE_SIZE          128   // Flash page size in bytes
#define EEPROM_PAGE_SIZE         4     // EEPROM page size in bytes
#define MAX_FLASH_ADDRESS        0x8000 // 32KB flash memory
#define BOOT_SECTION_START       0x7000 // Do not write to bootloader section

/* Include the hex file data */
#include "arduino_hex.h"

/* APPLICATION START */

/* Includes ------------------------------------------------------------------*/
#include "main.h"
#include "usart.h"
#include "gpio.h"
#include <stdio.h>
#include <string.h>
#include <stdbool.h>

/* Private typedef -----------------------------------------------------------*/
typedef enum {
  LOG_STM_TO_ARDUINO,  // Messages from STM to Arduino
  LOG_ARDUINO_TO_STM   // Messages from Arduino to STM
} LogType;

typedef enum {
  MEMORY_TYPE_FLASH,
  MEMORY_TYPE_EEPROM,
  MEMORY_TYPE_FUSE
} MemoryType;

typedef struct {
  uint32_t address;      // Current memory address
  uint8_t *data;         // Pointer to data buffer
  uint16_t size;         // Size of data in buffer
  MemoryType type;       // Type of memory being programmed
} ProgrammingState;

/* Private define ------------------------------------------------------------*/
// UARTs
#define UART_ARDUINO    huart1  // Connected to Arduino hardware
#define UART_DEBUG      huart2  // Connected to PL2303 for debug via Putty

/* Private variables ---------------------------------------------------------*/
uint8_t rxBuffer[RX_BUFFER_SIZE];
uint8_t txBuffer[RX_BUFFER_SIZE];
char debugBuffer[DEBUG_BUFFER_SIZE];
uint32_t tickStart;
uint8_t dtrState = 0;
uint8_t prevDtrState = 0;

/* Private function prototypes -----------------------------------------------*/
void SystemClock_Config(void);
void ResetArduino(void);
bool ResetAndSyncArduino(uint8_t attempts);
void LogMessage(LogType type, uint8_t* buffer, uint16_t size);
bool IsSync(uint8_t* buffer, uint16_t size);
bool SendDirectSync(void);
bool SendSyncWithRetries(uint8_t retries);

/* Function prototypes for hex upload */
bool EnterProgrammingMode(void);
bool LeaveProgrammingMode(void);
bool SendCommandAndWaitForSync(uint8_t cmd, uint8_t *params, uint8_t paramSize, uint8_t *response, uint8_t responseSize);
bool LoadAddress(uint16_t address);
bool ProgramPage(uint8_t *data, uint16_t size, MemoryType type);
bool EraseChip(void);
bool VerifySignature(void);
bool UploadHexFile(void);
void PrintUploadProgress(uint32_t currentAddress, uint32_t totalSize);

/* Private user code ---------------------------------------------------------*/

/**
  * @brief Reset Arduino UNO into bootloader mode with precise timing for ATmega328P
  * @retval None
  */
void ResetArduino(void)
{
  // Log the reset action start
  sprintf(debugBuffer, "[%lu] SYSTEM: Arduino UNO reset sequence initiated\r\n", HAL_GetTick());
  HAL_UART_Transmit(&UART_DEBUG, (uint8_t*)debugBuffer, strlen(debugBuffer), UART_TIMEOUT);

  // UNO/ATmega328P specific bootloader entry sequence:

  // 1. Set RESET low (Arduino enters reset)
  HAL_GPIO_WritePin(ARDUINO_RESET_PORT, ARDUINO_RESET_PIN, GPIO_PIN_RESET);

  // 2. Hold reset for much longer to ensure the LED visibly blinks (2 seconds)
  HAL_Delay(RESET_PULSE_DURATION);

  // 3. Release RESET - bootloader starts immediately after release
  HAL_GPIO_WritePin(ARDUINO_RESET_PORT, ARDUINO_RESET_PIN, GPIO_PIN_SET);

  // 4. Wait longer for the bootloader to initialize properly
  HAL_Delay(POST_RESET_DELAY);

  // Log the reset action completion
  sprintf(debugBuffer, "[%lu] SYSTEM: Arduino UNO reset sequence completed - bootloader window active\r\n", HAL_GetTick());
  HAL_UART_Transmit(&UART_DEBUG, (uint8_t*)debugBuffer, strlen(debugBuffer), UART_TIMEOUT);
}

/**
  * @brief Log message with timestamp and direction
  * @param type: Type of message (direction)
  * @param buffer: Message content
  * @param size: Message size
  * @retval None
  */
void LogMessage(LogType type, uint8_t* buffer, uint16_t size)
{
  uint32_t timestamp = HAL_GetTick();
  char prefix[32];

  // Determine message prefix based on type
  switch(type) {
    case LOG_STM_TO_ARDUINO:
      strcpy(prefix, "STM->ARDUINO");
      break;
    case LOG_ARDUINO_TO_STM:
      strcpy(prefix, "ARDUINO->STM");
      break;
    default:
      strcpy(prefix, "UNKNOWN");
  }

  // Format the log header with timestamp and direction
  sprintf(debugBuffer, "[%lu] %s: ", timestamp, prefix);
  uint16_t headerLen = strlen(debugBuffer);

  // Send log header
  HAL_UART_Transmit(&UART_DEBUG, (uint8_t*)debugBuffer, headerLen, UART_TIMEOUT);

  // For binary data, output hex values
  for (uint16_t i = 0; i < size; i++) {
    sprintf(debugBuffer, "0x%02X ", buffer[i]);
    HAL_UART_Transmit(&UART_DEBUG, (uint8_t*)debugBuffer, strlen(debugBuffer), UART_TIMEOUT);
  }

  // Add newline
  HAL_UART_Transmit(&UART_DEBUG, (uint8_t*)"\r\n", 2, UART_TIMEOUT);
}

/**
  * @brief Check if buffer contains an avrdude sync request
  * @param buffer: Buffer to check
  * @param size: Buffer size
  * @retval true if sync request is detected
  */
bool IsSync(uint8_t* buffer, uint16_t size)
{
  // Check for the standard STK500 sync pattern (0x30, 0x20)
  if (size >= 2 && buffer[0] == STK_GET_SYNC && buffer[1] == STK_GET_SYNC_EXT)
    return true;

  // Check for alternate sync patterns
  if (size >= 2 && buffer[0] == STK_GET_SYNC && buffer[1] == 0x00)
    return true;

  // For UNO, sometimes just the first byte is enough to check
  if (size >= 1 && buffer[0] == STK_GET_SYNC)
    return true;

  return false;
}

/**
  * @brief Send a sync command directly to Arduino bootloader
  * @retval true if sync response received
  */
bool SendDirectSync(void)
{
  uint8_t syncCmd[2] = {STK_GET_SYNC, STK_GET_SYNC_EXT};
  uint8_t response[2] = {0, 0};
  bool success = false;

  // Log action
  sprintf(debugBuffer, "[%lu] SYSTEM: Sending direct sync command to bootloader\r\n", HAL_GetTick());
  HAL_UART_Transmit(&UART_DEBUG, (uint8_t*)debugBuffer, strlen(debugBuffer), UART_TIMEOUT);

  // Flush any existing data in the UART buffers
  HAL_UART_AbortReceive(&UART_ARDUINO);

  // Wait for UART to stabilize
  HAL_Delay(10);

  // Send sync command
  HAL_UART_Transmit(&UART_ARDUINO, syncCmd, 2, UART_TIMEOUT);

  // Try to receive first byte with longer timeout
  if (HAL_UART_Receive(&UART_ARDUINO, &response[0], 1, SYNC_RESPONSE_TIMEOUT) == HAL_OK) {
    // We got the first byte, check if it's STK_INSYNC
    if (response[0] == STK_INSYNC) {
      sprintf(debugBuffer, "[%lu] SYSTEM: Received STK_INSYNC (0x%02X)\r\n", HAL_GetTick(), response[0]);
      HAL_UART_Transmit(&UART_DEBUG, (uint8_t*)debugBuffer, strlen(debugBuffer), UART_TIMEOUT);

      // Try to get the second byte (STK_OK) with dedicated timeout
      if (HAL_UART_Receive(&UART_ARDUINO, &response[1], 1, SECOND_BYTE_TIMEOUT) == HAL_OK) {
        sprintf(debugBuffer, "[%lu] SYSTEM: Received second byte: 0x%02X\r\n", HAL_GetTick(), response[1]);
        HAL_UART_Transmit(&UART_DEBUG, (uint8_t*)debugBuffer, strlen(debugBuffer), UART_TIMEOUT);

        if (response[1] == STK_OK) {
          sprintf(debugBuffer, "[%lu] SYSTEM: Second byte is STK_OK - Bootloader sync confirmed!\r\n", HAL_GetTick());
          HAL_UART_Transmit(&UART_DEBUG, (uint8_t*)debugBuffer, strlen(debugBuffer), UART_TIMEOUT);
          success = true;
        } else {
          sprintf(debugBuffer, "[%lu] SYSTEM: Second byte is not STK_OK\r\n", HAL_GetTick());
          HAL_UART_Transmit(&UART_DEBUG, (uint8_t*)debugBuffer, strlen(debugBuffer), UART_TIMEOUT);
        }
      } else {
        sprintf(debugBuffer, "[%lu] SYSTEM: No second byte received after STK_INSYNC\r\n", HAL_GetTick());
        HAL_UART_Transmit(&UART_DEBUG, (uint8_t*)debugBuffer, strlen(debugBuffer), UART_TIMEOUT);
      }
    } else {
      sprintf(debugBuffer, "[%lu] SYSTEM: Received 0x%02X instead of STK_INSYNC\r\n", HAL_GetTick(), response[0]);
      HAL_UART_Transmit(&UART_DEBUG, (uint8_t*)debugBuffer, strlen(debugBuffer), UART_TIMEOUT);
    }
  } else {
    sprintf(debugBuffer, "[%lu] SYSTEM: No response from bootloader\r\n", HAL_GetTick());
    HAL_UART_Transmit(&UART_DEBUG, (uint8_t*)debugBuffer, strlen(debugBuffer), UART_TIMEOUT);
  }

  return success;
}

/**
  * @brief  The application entry point.
  * @retval int
  */
int main(void)
{
  /* MCU Configuration--------------------------------------------------------*/
  HAL_Init();
  SystemClock_Config();

  /* Initialize all configured peripherals */
  MX_GPIO_Init();
  MX_USART1_UART_Init();
  MX_USART2_UART_Init();

  // Initialize Arduino reset pin to high (not in reset)
  HAL_GPIO_WritePin(ARDUINO_RESET_PORT, ARDUINO_RESET_PIN, GPIO_PIN_SET);
  HAL_Delay(500); // Initial delay to stabilize

  // Send startup message to debug UART
  sprintf(debugBuffer, "[%lu] SYSTEM: STM32 USB-Serial bridge for Arduino UNO started\r\n", HAL_GetTick());
  HAL_UART_Transmit(&UART_DEBUG, (uint8_t*)debugBuffer, strlen(debugBuffer), UART_TIMEOUT);

  // UNO bootloader works at 115200 baud
  sprintf(debugBuffer, "[%lu] SYSTEM: Target: Arduino UNO (ATmega328P) at 115200 baud\r\n", HAL_GetTick());
  HAL_UART_Transmit(&UART_DEBUG, (uint8_t*)debugBuffer, strlen(debugBuffer), UART_TIMEOUT);

  // Attempt to upload hex file
  sprintf(debugBuffer, "[%lu] SYSTEM: Starting Arduino hex file upload\r\n", HAL_GetTick());
  HAL_UART_Transmit(&UART_DEBUG, (uint8_t*)debugBuffer, strlen(debugBuffer), UART_TIMEOUT);

  if (UploadHexFile()) {
    sprintf(debugBuffer, "[%lu] SYSTEM: Upload successful - Arduino is now running the new program\r\n", HAL_GetTick());
    HAL_UART_Transmit(&UART_DEBUG, (uint8_t*)debugBuffer, strlen(debugBuffer), UART_TIMEOUT);
  } else {
    sprintf(debugBuffer, "[%lu] SYSTEM: Upload failed - Check connections and retry\r\n", HAL_GetTick());
    HAL_UART_Transmit(&UART_DEBUG, (uint8_t*)debugBuffer, strlen(debugBuffer), UART_TIMEOUT);
  }

  // Infinite loop after completing upload
  while (1) {
    // Check for data from Arduino
    if (HAL_UART_Receive(&UART_ARDUINO, rxBuffer, 1, 10) == HAL_OK) {
      // Got at least one byte, check for more with short timeout
      uint16_t rxSize = 1;

      // Try to receive more bytes that might be in the buffer (with short timeout)
      while (rxSize < RX_BUFFER_SIZE &&
             HAL_UART_Receive(&UART_ARDUINO, &rxBuffer[rxSize], 1, 2) == HAL_OK) {
        rxSize++;
      }

      // Log data received from Arduino
      LogMessage(LOG_ARDUINO_TO_STM, rxBuffer, rxSize);
    }

    // Blink an LED or perform other maintenance tasks
    HAL_Delay(100);
  }
}

/**
  * @brief Send sync commands with multiple retries
  * @param retries: Number of sync command retries
  * @retval true if sync was achieved
  */
bool SendSyncWithRetries(uint8_t retries)
{
  bool syncSuccess = false;

  for (uint8_t i = 0; i < retries; i++) {
    sprintf(debugBuffer, "[%lu] SYSTEM: Sync attempt %d of %d\r\n", HAL_GetTick(), i+1, retries);
    HAL_UART_Transmit(&UART_DEBUG, (uint8_t*)debugBuffer, strlen(debugBuffer), UART_TIMEOUT);

    if (SendDirectSync()) {
      syncSuccess = true;
      break;
    }

    // Wait before trying again
    if (i < retries - 1) {
      HAL_Delay(SYNC_RETRY_DELAY);
    }
  }

  return syncSuccess;
}

/**
  * @brief Perform multiple reset attempts to ensure bootloader entry
  * @param attempts: Number of reset attempts
  * @retval true if sync was achieved
  */
bool ResetAndSyncArduino(uint8_t attempts)
{
  bool syncAchieved = false;

  for (uint8_t i = 0; i < attempts; i++) {
    // Log attempt number if multiple attempts
    if (attempts > 1) {
      sprintf(debugBuffer, "[%lu] SYSTEM: Reset attempt %d of %d\r\n", HAL_GetTick(), i+1, attempts);
      HAL_UART_Transmit(&UART_DEBUG, (uint8_t*)debugBuffer, strlen(debugBuffer), UART_TIMEOUT);
    }

    // Reset Arduino
    ResetArduino();

    // Try multiple sync commands after each reset
    if (SendSyncWithRetries(ARDUINO_SYNC_RETRIES)) {
      sprintf(debugBuffer, "[%lu] SYSTEM: Bootloader sync achieved on reset attempt %d!\r\n", HAL_GetTick(), i+1);
      HAL_UART_Transmit(&UART_DEBUG, (uint8_t*)debugBuffer, strlen(debugBuffer), UART_TIMEOUT);
      syncAchieved = true;
      break;
    }

    // If this wasn't the last attempt, wait before trying again
    if (i < attempts - 1) {
      sprintf(debugBuffer, "[%lu] SYSTEM: Sync failed, waiting before next reset attempt...\r\n", HAL_GetTick());
      HAL_UART_Transmit(&UART_DEBUG, (uint8_t*)debugBuffer, strlen(debugBuffer), UART_TIMEOUT);
      HAL_Delay(INTER_RESET_DELAY);
    }
  }

  if (!syncAchieved && attempts > 1) {
    sprintf(debugBuffer, "[%lu] SYSTEM: Failed to sync after %d reset attempts\r\n", HAL_GetTick(), attempts);
    HAL_UART_Transmit(&UART_DEBUG, (uint8_t*)debugBuffer, strlen(debugBuffer), UART_TIMEOUT);
  }

  return syncAchieved;
}
/**
  * @brief  Send STK500 command and wait for the INSYNC/OK response
  * @param  cmd: STK500 command byte
  * @param  params: Parameter buffer
  * @param  paramSize: Parameter buffer size
  * @param  response: Buffer to store any additional response data
  * @param  responseSize: Expected response data size (excluding INSYNC/OK bytes)
  * @retval true if command succeeded
  */
bool SendCommandAndWaitForSync(uint8_t cmd, uint8_t *params, uint8_t paramSize, uint8_t *response, uint8_t responseSize)
{
  uint8_t cmdBuffer[RX_BUFFER_SIZE];
  uint8_t respBuffer[2 + RX_BUFFER_SIZE]; // INSYNC + OK + any response data
  bool success = false;

  // Prepare command buffer
  cmdBuffer[0] = cmd;

  // Copy parameters if any
  if (params != NULL && paramSize > 0) {
    memcpy(&cmdBuffer[1], params, paramSize);
  }

  // Add Sync_CRC_EOP byte at the end
  cmdBuffer[1 + paramSize] = 0x20;  // Sync_CRC_EOP

  // Total command size is: 1 byte command + paramSize + 1 byte Sync_CRC_EOP
  uint8_t totalSize = 1 + paramSize + 1;

  // Log command with detailed hex values
  sprintf(debugBuffer, "[%lu] UPLOAD: Sending command 0x%02X with %d params + Sync_CRC_EOP\r\n",
          HAL_GetTick(), cmd, paramSize);
  HAL_UART_Transmit(&UART_DEBUG, (uint8_t*)debugBuffer, strlen(debugBuffer), UART_TIMEOUT);

  // For detailed debugging, log the exact bytes being sent
  sprintf(debugBuffer, "[%lu] UPLOAD: Raw bytes: ", HAL_GetTick());
  HAL_UART_Transmit(&UART_DEBUG, (uint8_t*)debugBuffer, strlen(debugBuffer), UART_TIMEOUT);

  for (int i = 0; i < totalSize; i++) {
    sprintf(debugBuffer, "0x%02X ", cmdBuffer[i]);
    HAL_UART_Transmit(&UART_DEBUG, (uint8_t*)debugBuffer, strlen(debugBuffer), UART_TIMEOUT);
  }

  sprintf(debugBuffer, "\r\n");
  HAL_UART_Transmit(&UART_DEBUG, (uint8_t*)debugBuffer, strlen(debugBuffer), UART_TIMEOUT);

  // Flush any existing data in the UART buffers
  HAL_UART_AbortReceive(&UART_ARDUINO);

  // Wait for UART to stabilize
  HAL_Delay(10);

  // Send command + parameters + Sync_CRC_EOP
  HAL_UART_Transmit(&UART_ARDUINO, cmdBuffer, totalSize, UART_TIMEOUT);

  // Try to receive first byte with longer timeout (INSYNC)
  if (HAL_UART_Receive(&UART_ARDUINO, &respBuffer[0], 1, SYNC_RESPONSE_TIMEOUT) == HAL_OK) {
    // We got the first byte, check if it's STK_INSYNC
    if (respBuffer[0] == STK_INSYNC) {
      sprintf(debugBuffer, "[%lu] UPLOAD: Received STK_INSYNC (0x%02X)\r\n", HAL_GetTick(), respBuffer[0]);
      HAL_UART_Transmit(&UART_DEBUG, (uint8_t*)debugBuffer, strlen(debugBuffer), UART_TIMEOUT);

      // Receive additional response data if expected
      if (response != NULL && responseSize > 0) {
        // Process response data one byte at a time with logging
        for (uint8_t i = 0; i < responseSize; i++) {
          if (HAL_UART_Receive(&UART_ARDUINO, &response[i], 1, UART_TIMEOUT) != HAL_OK) {
            sprintf(debugBuffer, "[%lu] UPLOAD: Failed to receive response byte %d\r\n", HAL_GetTick(), i+1);
            HAL_UART_Transmit(&UART_DEBUG, (uint8_t*)debugBuffer, strlen(debugBuffer), UART_TIMEOUT);
            return false;
          }

          sprintf(debugBuffer, "[%lu] UPLOAD: Response byte %d: 0x%02X\r\n", HAL_GetTick(), i+1, response[i]);
          HAL_UART_Transmit(&UART_DEBUG, (uint8_t*)debugBuffer, strlen(debugBuffer), UART_TIMEOUT);
        }
      }

      // Try to get the final byte (STK_OK) with dedicated timeout
      if (HAL_UART_Receive(&UART_ARDUINO, &respBuffer[1], 1, SECOND_BYTE_TIMEOUT) == HAL_OK) {
        sprintf(debugBuffer, "[%lu] UPLOAD: Received final byte: 0x%02X\r\n", HAL_GetTick(), respBuffer[1]);
        HAL_UART_Transmit(&UART_DEBUG, (uint8_t*)debugBuffer, strlen(debugBuffer), UART_TIMEOUT);

        if (respBuffer[1] == STK_OK) {
          sprintf(debugBuffer, "[%lu] UPLOAD: Command 0x%02X completed successfully!\r\n", HAL_GetTick(), cmd);
          HAL_UART_Transmit(&UART_DEBUG, (uint8_t*)debugBuffer, strlen(debugBuffer), UART_TIMEOUT);
          success = true;
        } else {
          sprintf(debugBuffer, "[%lu] UPLOAD: Final byte is not STK_OK\r\n", HAL_GetTick());
          HAL_UART_Transmit(&UART_DEBUG, (uint8_t*)debugBuffer, strlen(debugBuffer), UART_TIMEOUT);
        }
      } else {
        sprintf(debugBuffer, "[%lu] UPLOAD: No final byte received after STK_INSYNC\r\n", HAL_GetTick());
        HAL_UART_Transmit(&UART_DEBUG, (uint8_t*)debugBuffer, strlen(debugBuffer), UART_TIMEOUT);
      }
    } else {
      sprintf(debugBuffer, "[%lu] UPLOAD: Received 0x%02X instead of STK_INSYNC\r\n", HAL_GetTick(), respBuffer[0]);
      HAL_UART_Transmit(&UART_DEBUG, (uint8_t*)debugBuffer, strlen(debugBuffer), UART_TIMEOUT);
    }
  } else {
    sprintf(debugBuffer, "[%lu] UPLOAD: No response from bootloader\r\n", HAL_GetTick());
    HAL_UART_Transmit(&UART_DEBUG, (uint8_t*)debugBuffer, strlen(debugBuffer), UART_TIMEOUT);
  }

  return success;
}
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

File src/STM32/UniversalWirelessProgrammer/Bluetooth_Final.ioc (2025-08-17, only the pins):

Mcu.UserName=STM32F401RETx
PA10.Signal=USART1_RX
PA13.GPIO_Label=TMS
PA13.Signal=SYS_JTMS-SWDIO
PA14.GPIO_Label=TCK
PA14.Signal=SYS_JTCK-SWCLK
PA2.GPIO_Label=USART_TX
PA2.Signal=USART2_TX
PA3.GPIO_Label=USART_RX
PA3.Signal=USART2_RX
PA5.GPIO_Label=LD2 [Green Led]
PA5.Signal=GPIO_Output
PA9.Signal=USART1_TX
PB3.GPIO_Label=SWO
PB3.Signal=SYS_JTDO-SWO
PB4.Signal=GPIO_Output
PC13-ANTI_TAMP.GPIO_Label=B1 [Blue PushButton]
PC13-ANTI_TAMP.Signal=GPXTI13
PC14-OSC32_IN.Signal=RCC_OSC32_IN
PC15-OSC32_OUT.Signal=RCC_OSC32_OUT
PC6.Signal=USART6_TX
PC7.Signal=USART6_RX

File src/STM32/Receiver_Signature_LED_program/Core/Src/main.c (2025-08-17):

#include "main.h"
#include "usart.h"
#include "usb_host.h"
#include "gpio.h"
#include <string.h>
#include "stdio.h"


#define BUFFER_SIZE 1024  // Define a buffer size
#define MAX_BOARD_NAME_LENGTH 50
char detected_board_name[MAX_BOARD_NAME_LENGTH] = "No Device";  // Store the detected board name
#define STK_GET_SYNC       0x30

uint8_t receivedData; // To store the received data
uint8_t receivedBuffer[BUFFER_SIZE];  // Buffer to hold received data
uint16_t bufferIndex = 0;  // Index to track the position in the buffer

uint8_t selected_board_name[MAX_BOARD_NAME_LENGTH]; //board name

#define HEX_LENGTH 17500
uint8_t hex_file[HEX_LENGTH]; //board name
uint16_t hexIndex = 0;
#define RX_BUFF_SIZE 64
uint8_t CDC_RX_Buffer[RX_BUFF_SIZE];
uint8_t CDC_TX_Buffer[RX_BUFF_SIZE];

int count =0; // flag showing cleared milestone 1 (END1)
int hex_received =0;
int signature_match=0;

volatile uint8_t upload_requested = 0; // Flag to track upload button state

void SystemClock_Config(void);
void MX_USB_HOST_Process(void);

void process_upload_request(void);
void update_status_led(void);


void TurnOnLED(void) {
    HAL_GPIO_WritePin(GPIOA, GPIO_PIN_5, GPIO_PIN_SET); // Turn LED ON
}

void TurnOffLED(void) {
    HAL_GPIO_WritePin(GPIOA, GPIO_PIN_5, GPIO_PIN_RESET); // Turn LED OFF
}

int main(void)
{
  HAL_Init();
  SystemClock_Config();
  MX_GPIO_Init();
  MX_USART1_UART_Init();
  MX_USART2_UART_Init();
  MX_USB_HOST_Init();

  HAL_UART_Init(&huart2);
  HAL_UART_Receive_IT(&huart1, &receivedData, 1);
  while (1)
   {
       MX_USB_HOST_Process();  // Process USB tasks

       const char* detected_device = check_usb_device();

       strncpy(detected_board_name, detected_device, MAX_BOARD_NAME_LENGTH - 1);
       detected_board_name[MAX_BOARD_NAME_LENGTH - 1] = '\0'; // Ensure null termination

       if (strcmp(detected_board_name, "No Device") == 0) {
           TurnOffLED();  // No device detected, turn off LED
       }
       else {
           if (strcmp(detected_board_name, (char*)selected_board_name) == 0) {
//              printf("Detected board matches the selected board: %s\r\n", detected_board_name);
               TurnOnLED();  // ✅ Turn on LED for a matching board
               signature_match = 1;
           } else {
              // printf("Board mismatch! Detected: %s, Selected: %s\r\n", detected_board_name, (char*)selected_board_name);
               TurnOffLED();  // ❌ Turn off LED for mismatch
               signature_match=0;
           }
       }
       int upload_requested = 0;
       if(signature_match==1 && hex_received ==1 && upload_requested == 0){
    	   HAL_UART_Transmit(&huart2, (uint8_t *)"upload_requested\r\n", 200, HAL_MAX_DELAY);
    	   process_upload_request();
    	   upload_requested = 1;
       }
       HAL_Delay(100);
   }
}

void process_upload_request(void) //FSM implementation
{

  ArduinoProgrammingState prog_state = get_programming_state();

  while(prog_state != ARDUINO_PROG_COMPLETED)
  {
	  if(prog_state == ARDUINO_PROG_IDLE){
		  printf("IDLE STATE\r\n");
		  trigger_arduino_bootloader();
		  prog_state = get_programming_state();
	  }

	  else if (prog_state == ARDUINO_PROG_RESET_SENT) {
		  printf("RESET SENT\r\n");
          if(send_stk_command(STK_GET_SYNC, NULL, 0) == USBH_OK){
          } else{
        	  printf("command not sent");
          }
		  prog_state = get_programming_state();
	  }
	  else if(prog_state == ARDUINO_WAIT_RESPONSE){
		  memset(CDC_RX_Buffer, 0, RX_BUFF_SIZE);
		  receive_stk_response(CDC_RX_Buffer);
		  prog_state = get_programming_state();

	  }
	  else if (prog_state == ARDUINO_PROG_BOOTLOADER_READY) {
		  printf("Boothloader in SYNC\r\n");
          program_hex_file((const char*)hex_file, strlen((char*)hex_file));
		  prog_state = get_programming_state();
	  }

	  else if (prog_state == ARDUINO_PROG_PROGRAMMED){
		  printf("Programmed\r\n");
          verify_hex_file((const char*)hex_file, strlen((char*)hex_file));
          prog_state = get_programming_state();
	  }

	  else if (prog_state == ARDUINO_PROG_VERIFIED){
		  printf("Verified\r\n");
          reset_programming_state();
          prog_state = get_programming_state();
	  }

	  else if (prog_state == ARDUINO_PROG_ERROR){
		  printf("Error Programming\r\n");
          reset_programming_state();
          prog_state = get_programming_state();
	  }

	  else {
		  printf("Unknown state\r\n");
		  reset_programming_state();
		  prog_state = get_programming_state();
	  }

  }

}



void SystemClock_Config(void)
{
  RCC_OscInitTypeDef RCC_OscInitStruct = {0};
  RCC_ClkInitTypeDef RCC_ClkInitStruct = {0};

  __HAL_RCC_PWR_CLK_ENABLE();
  __HAL_PWR_VOLTAGESCALING_CONFIG(PWR_REGULATOR_VOLTAGE_SCALE2);

  RCC_OscInitStruct.OscillatorType = RCC_OSCILLATORTYPE_HSE;
  RCC_OscInitStruct.HSEState = RCC_HSE_ON;
  RCC_OscInitStruct.PLL.PLLState = RCC_PLL_ON;
  RCC_OscInitStruct.PLL.PLLSource = RCC_PLLSOURCE_HSE;
  RCC_OscInitStruct.PLL.PLLM = 4;
  RCC_OscInitStruct.PLL.PLLN = 72;
  RCC_OscInitStruct.PLL.PLLP = RCC_PLLP_DIV2;
  RCC_OscInitStruct.PLL.PLLQ = 3;
  if (HAL_RCC_OscConfig(&RCC_OscInitStruct) != HAL_OK)
  {
    Error_Handler();
  }
  RCC_ClkInitStruct.ClockType = RCC_CLOCKTYPE_HCLK|RCC_CLOCKTYPE_SYSCLK
                              |RCC_CLOCKTYPE_PCLK1|RCC_CLOCKTYPE_PCLK2;
  RCC_ClkInitStruct.SYSCLKSource = RCC_SYSCLKSOURCE_PLLCLK;
  RCC_ClkInitStruct.AHBCLKDivider = RCC_SYSCLK_DIV1;
  RCC_ClkInitStruct.APB1CLKDivider = RCC_HCLK_DIV2;
  RCC_ClkInitStruct.APB2CLKDivider = RCC_HCLK_DIV1;

  if (HAL_RCC_ClockConfig(&RCC_ClkInitStruct, FLASH_LATENCY_2) != HAL_OK)
  {
    Error_Handler();
  }
}
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
